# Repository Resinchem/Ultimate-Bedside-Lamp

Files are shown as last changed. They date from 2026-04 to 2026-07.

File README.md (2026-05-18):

# Ultimate Bedside Lamp
<div align="center">

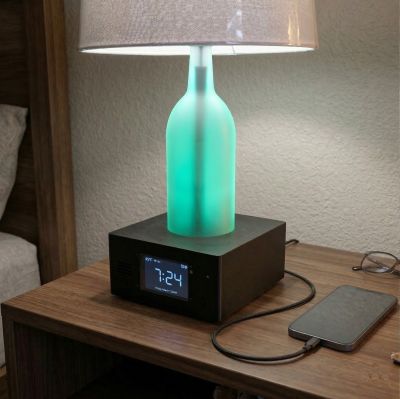
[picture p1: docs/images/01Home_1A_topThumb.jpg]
lamp_image

</div>

## Key Features
- **Integrated Hardware:** A single device providing lighting, clock and alarm functions.
   * Three independent ESP-based controllers act together as a single device
- **Versatile Lighting:** Indivdually controllable RGBW bulb and LED Strip for "normal" and "night" modes.
   * Each light source can have independent state, color and brightness settings
- **High-End Display:** Auto-dimming touch screen with configurable fonts, colors and sizes
   * Show time in 12 or 24-hour format.  Outdoor or indoor temperature in °F or °C.
   * Configurable dimming levels based on measured ambient light levels
   * Control lighting, set alarms and more right from the touch panel
- **Dual Touch Sensors:** Up to two configurable touch sensors
   * _Primary functions_: Toggle the lights, or change brightness of lights or the display with a simply tap.
   * _Special Alarm functions_: Buttons can automatically become alarm snooze/stop buttons when alarm sounds.
- **Advanced Alarms:** Define up to five active alarms
   * Allows long-term advanced scheduling and multiple active alarms can co-exist
   * **Gentle Wake Option:** Alarm sounds quietly and slowly increases in volume.
   * Selectable Alarm Sounds: Use one of the provided sounds or provide your own MP3 sounds
   * Customizable Snooze Range: Set your snooze time from 0-60 minutes.
- **Flexible Control Options**: Multiple methods provided for interacting with the system.
   * Single integrated web app 
   * Local touch controls via display and optional touch sensors
   * _Optionally_ integrate and control from external systems (e.g. Home Assistant, NodeRED, etc.)
- **Smart Integration**: Mutliple methods to _optionally_ interface with external systems
   * MQTT or HTTP API for exchanging data and controlling many features of the system.
   * **Home Assistant**: One-click integration with Home Assistant.  No configuration or YAML needed!
- **Local Control:** Only WIFI needed for full basic functionality.  Internet-based data use is **optional**
   * _Optionally_ sync time to an external NTP server (but also supports local server)
   * _Optionally_ get current weather/temperature from OpenWeatherSource (OWS)
- **Device Charging**: Dual USB ports for charging two devices simultaneously

### Guides, Instructions and More Information

- [Video Overview](https://youtu.be/4I0m3b1LWYo) - video overview of the project (YouTube)
- [Build Information](https://resinchemtech.blogspot.com/2026/04/ultimate-bedside-lamp.html) - written guide with parts list, wiring diagrams and general build instructions
- [Firmware Guide](https://resinchem.github.io/Ultimate-Bedside-Lamp/) - Instructions for installing, configuring and using the firmware and integrated web application.

Please review the above carefully.  For reasons described, this project expects a very specific set of hardware.  Substitutions will likely require firmware modifications.

**_I do not have the bandwidth to maintain multiple versions of the firmware for different hardware combinations. <br>Please do not submit issues requesting support for alternate hardware._** 

### Questions?
Can't find an answer above?  Please post your question in the [Discussion](https://github.com/Resinchem/Ultimate-Bedside-Lamp/discussions) are of the repository.  I will do my best to provide guidance as time allows.

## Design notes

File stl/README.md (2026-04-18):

## 3D Printed Parts Design Files
These are my design files (.stl) for the various 3D printed parts used. They were all creating using the simple, free Tinkercad web application and there is substantial room for improvement or redesign for someone with more talent than me!

|Part |Qty|Supports*|Est. Print Time* | Est. Filament*
|-----|:---:|:---:|:---:|:---:
|`Bottle Adapter.stl`|1|no|1 hour|5g
|`Bottle Center Shaft.stl`|1|no |7 hours| 40g
|`Bottle Platform.stl`|1|YES|3.5 hours| 30g
|`Bottle Sizer`|_optional_|no|2 hours|10g
|`Main Enclosure Base`|1|YES|**41 hours**|300g
|`Main Enclosure Lid`|1|no|10 hours| 90g
|`Midplatform Support`|1|no|1.5 hours|10g
|`USBPort Mount`|2|no|1 hour|6g
|`USBPort Nut`|2|no|1 hour|4g

- I used black PLA for all parts, but other materials/colors can be used if desired.  
- Estimates based on my printer and settings.  Yours may vary.
- Click on any .stl file above to see a 3D-generated preview of the part

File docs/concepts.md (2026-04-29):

---
layout: default
title: Concepts and Terminology
parent: Welcome
nav_order: 2
has_toc: false
---

# Concepts and Terminology
{: .no_toc }

To successfully install and configure this firmware, it is important to understand the underlying system design and the specific terminology used throughout this documentation.

**🌐 Connectivity & Privacy:**<br>This system is designed to be **fully functional on a local Wi-Fi network**. While it supports integrations like Home Assistant, Open Weather Map, and NTP time-syncing, these are strictly **optional**. An active internet connection is not required for core operations.
{: .note }

---

## The Controller Triumvirate
<p align="center">
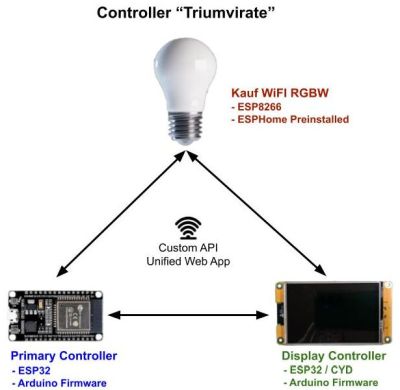
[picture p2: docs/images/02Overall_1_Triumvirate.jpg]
  
</p>
The "Ultimate Bedside Lamp" is not a single device, but a coordinated system of three separate controllers communicating via a custom internal API.

### 1. RGBW Wi-Fi Light Bulb
The bulb is the system's "Silent Partner." It arrives with a specialized version of ESPHome pre-installed, and it expects the rest of the world to keep up with its specific API. Think of it as the talented lead singer of the band who refuses to learn the other members' names—as long as the Primary Controller sends the right commands, the bulb performs beautifully. Just don't try to "re-educate" it with different firmware unless you're prepared for a very quiet (and dark) room. 

* **No Dependency:** You do **not** need to be a Home Assistant user or have an ESPHome server to use this bulb. It only requires a local Wi-Fi connection.
* **Integration:** If you are a Home Assistant user, you can _optionally_ import the bulb as an ESPHome node. Note that if you also integrate the Primary Controller via MQTT or Home Assistant Discovery, you may see duplicate entities for the bulb.
* **Firmware:** No flashing is required for the bulb. You will only need to complete the Wi-Fi onboarding process.

### 2. Primary Controller
This is a standard 30-pin **ESP32 WROOM32** running the custom Arduino-based firmware found in this repository. 
* **Action Required:** You must flash the provided firmware to this board and complete the onboarding process to join it to your local network.

Throughout this document, this controller is referred to as the **"Primary"** or **"Main"** controller.

### 3. Display Controller
This is a "Cheap Yellow Display" (CYD) featuring an integrated ESP32 and a 3.5" screen.

**⚠️ Critical Hardware Requirement**<br>The firmware is compiled specifically for the **Capacitive Touch** version of the 3.5" CYD linked in the build guide. This firmware **will not work** with resistive touch displays. Using a different display will require significant changes to the `TFT_eSPI` library and a full code recompilation.
{: .note }

* **Action Required**: Like the Primary Controller, this board requires flashing the firmware from the repository and Wi-Fi onboarding. 

This controller is always referred to as the **"Display"** or **"Secondary"** controller.

---

## Main Functions by Controller

The diagram below illustrates how responsibilities are divided across the three devices:

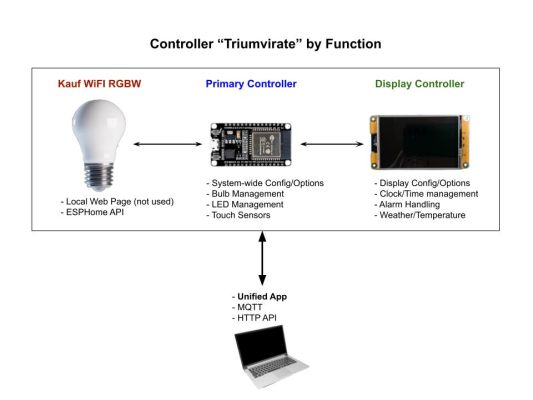
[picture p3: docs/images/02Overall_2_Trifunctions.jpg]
Controller By Function


### Unified Operation
While the hardware is split into three parts, the user experience is seamless:
* **Unified Web App:** Once onboarded, you access and control the entire system through a single web interface.
* **Single API/MQTT Path:** The system internally routes commands (API or MQTT) to the correct controller, allowing you to treat the lamp as a single entity in your automation logic.

---

For build instructions and physical assembly details, please refer to the [written companion guide](https://resinchemtech.blogspot.com/2026/05/ultimate-bedside-lamp.html).

<div style="display: flex; justify-content: space-between; align-items: center; margin-top: 40px; border-top: 1px solid #333; padding-top: 20px;">
  <a href="{{ '/about' | relative_url }}" class="btn btn-outline"><- Previous: About the Project</a>
  <a href="{{ '/startingmain' | relative_url }}" class="btn btn-purple">Next: Getting Started -></a>
</div>

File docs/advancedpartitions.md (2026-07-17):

---
layout: default
title: Partitions and Flashing
parent: Advanced Technical Information
nav_order: 4
---

# Partitions and Flashing
{: .no_toc }

---

<p align="center">
  [Partitions image]
</p>

This information is critical if you are manually flashing source code via the Arduino IDE or a third-party utility. If you are simply using the web-based "Firmware Upgrade" feature with the provided `.bin` files, the system handles the memory offsets for you. However, for the developers out there, here is how we manage the "real estate" inside the ESP32.

### The "Sketch Too Large" Problem
Due to the complexity of the firmware and the inclusion of the web application strings, the binary is too large to fit into a standard ESP32 partition. To solve this, we "borrow" space normally reserved for the SPIFFS (the local file system). Since our configuration files are tiny JSON strings, we can safely shrink the SPIFFS area and give that extra room to the primary sketch.

**🖥️ Full vs. Update .bin Files**<br>This partitioning is why the releases contain both a **_Full.bin** and a **_Update.bin** file.  When flashing the **_Full.bin** file, the new partitions are created as part of the installation.  This will cause the destruction and loss of any pre-existing data, which is why upgrading an existing system with the **_Full.bin** file causes loss of the existing configuration.  Alternatively, attempting to install the **_Update.bin** file on a new board only updates the sketch area, but since the correct partitions do not exist, it gets written to the wrong area and generally results in a boot loop.
{: .note }

---

### Arduino IDE Configuration
When using the Arduino IDE to compile and flash the source code, you **must** change the partition scheme from the "Default" setting. Failure to do this will result in a compilation error stating that the firmware is too large for the available space.

In the **Tools** menu, ensure your settings match the following:

* **Board:** `ESP32 Dev Module`
* **Partition Scheme:** `Minimal SPIFFS (1.9MB APP with OTA/190KB SPIFFS)`

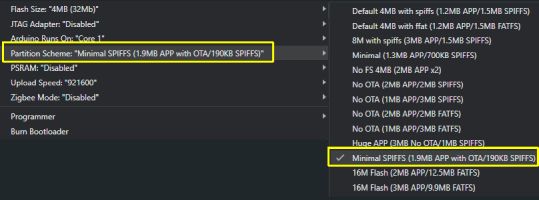
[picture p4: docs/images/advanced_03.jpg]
Arduino IDE Partition Settings


---

### Manual Partition Table
If you are using a different IDE or a specialized flashing utility (like the Espressif Download Tool), you will need the specific memory offsets and sizes. If these aren't set correctly, the ESP32 will likely fall into a "boot loop" as it tries to find its code in the wrong neighborhood.

| Partition Name | Type | Subtype | Offset | Size |
| :--- | :--- | :--- | :--- | :--- |
| **nvs** | data | nvs | `0x9000` | `0x5000` (20KB) |
| **otadata** | data | ota | `0xe000` | `0x2000` (8KB) |
| **app0** | app | ota_0 | `0x10000` | `0x1E0000` (1.875MB) |
| **app1** | app | ota_1 | `0x1F0000` | `0x1E0000` (1.875MB) |
| **spiffs** | data | spiffs | `0x3D0000` | `0x30000` (~190KB) |

> **💡 Fun Fact**<br>By using this "Minimal SPIFFS" layout, we still have two identical `app` slots (OTA0 and OTA1). This is what allows a controller to perform a "Safe Update"—it downloads the new firmware into the empty slot and only switches over if the download is successful. It’s like wearing a belt and suspenders at the same time!
{: .note }

---

<div style="display: flex; justify-content: space-between; align-items: center; margin-top: 40px; border-top: 1px solid #333; padding-top: 20px;">
  <a href="{{ '/advanceddisplay' | relative_url }}" class="btn btn-outline"><- Previous: Display Library and Fonts</a>
  <a href="{{ '/troubleshooting' | relative_url }}" class="btn btn-purple">Next: Troubleshooting -></a>
</div>

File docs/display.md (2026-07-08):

---
layout: default
title: Main Display
parent: Setting Up the System
nav_order: 2
---

# Display Settings and Options
{: .no_toc }

---

<p align="center">
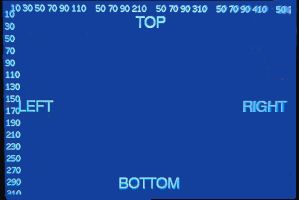
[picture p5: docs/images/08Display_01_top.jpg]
Main Display Overview
  
</p>

The main display is a 3.5" 'Cheap Yellow Display' (CYD) featuring capacitive touch and a resolution of 480x320 pixels. 

> **⚠️ Hardware Compatibility**<br>As detailed in the [Build Article](https://resinchemtech.blogspot.com/2026/05/ultimate-bedside-lamp.html), using a different display model will likely require firmware modifications, specifically within the **TFT_eSPI** library configuration. 
{: .important }

---

### Configuring the Display
To access the display settings, navigate to the **Display** section of the primary web application. Note that the interface will switch to the Display Controller, indicated by a pale yellow background.

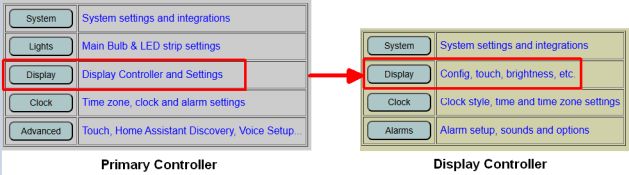
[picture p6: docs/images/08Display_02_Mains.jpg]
Display Interface Menu


The configuration page is divided into two sections. The top section manages the hardware behavior and orientation of the display itself.

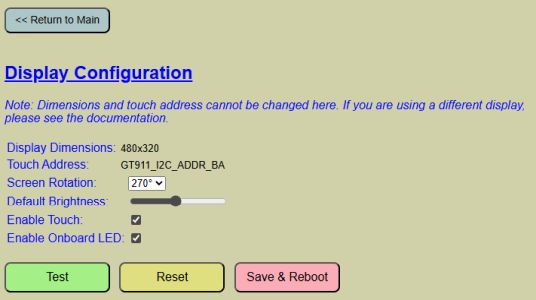
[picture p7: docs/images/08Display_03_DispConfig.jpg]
08_Display_03


#### Hardware Definitions
* **Dimensions & Touch Address:** These values are hard-coded in the TFT_eSPI library during firmware compilation and cannot be changed via the web app. If you are using non-standard hardware, refer to [Modifying the Firmware]({{ '/firmwaremain' | relative_url }}).
* **Screen Rotation:** Options include 0°, 90°, 180°, and 270° (Default). 
    * **Note:** The firmware is optimized for landscape (90°/270°). Portrait orientations may result in text being cut off. 

#### Operational Settings
* **Default Brightness:** Sets the initial brightness level after a reboot. If [Auto-Dimming]({{ '/autodim' | relative_url }}) is enabled, this value is overridden by ambient light levels, though it is still used as the "base" brightness when the screen is tapped.
* **Enable Touch:** This controls the capacitive touch features of the display. 
    > **⚠️ Warning**<br>If you disable this feature, you will lose the ability to access settings or menus directly via the display. Only uncheck this if your hardware does not support capacitive touch.
    {: .warning }
* **Enable Onboard LED:** If your display hardware includes a front-facing RGB LED, this option allows it to show system status.
    * **Yellow:** Booting/Process in progress.
    * **Green:** Successful connection/boot.
    * **Red:** Failure or Test Mode.
<br><br>
<p align="center">
  Main Display Overview
</p>

### Testing and Maintenance
The system provides built-in tools to verify your display and touch configuration without requiring a reboot.

* **TEST Button:** Activating this shows the visual boundaries of the screen, scale indicators, and lights the onboard LED red. 
* **Touch Testing:** If touch is enabled, you can drag your finger to draw lines, confirming the calibration and responsiveness of the screen.

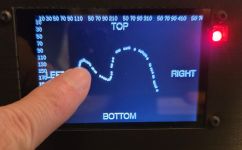
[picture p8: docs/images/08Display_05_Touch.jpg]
Touch Test Mode


* **RESET Button:** Reverts all unsaved changes on the page to the previously saved defaults.
* **SAVE AND REBOOT:** Commits current settings to the flash memory and restarts the controller to apply them. **Unsaved changes are lost if you navigate away from this page.**

---

### The Standard Clock Display
When idle, the display shows the clock and environmental data. Several status icons are positioned along the top edge:

<p align="center">
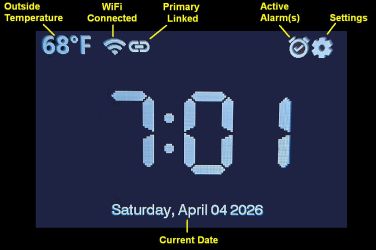
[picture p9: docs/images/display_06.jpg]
Clock Display Layout
  
</p>

* **Outside Temperature:** Displays the local outdoor temperature. This requires a configured source such as Open Weather Map, MQTT, or the HTTP API. Refer to [Temperature and Weather]({{ '/weather' | relative_url }}) for setup.
* **WiFi:** Indicates connection status. A slash indicates the display controller is offline WiFi Icon.
* **Primary Link:** Indicates a successful API connection to the Primary Controller. Shown with slash if not connectedLink Icon
* **Active Alarms:** Only appears when one or more alarms are scheduled and active.
* **Settings:** Tapping this icon enters the local settings menu for lighting and alarm control. Details can be found in [Using the System]({{ '/usingmain' | relative_url }}).
* **Time:** The core clock display. Font, color, and 12/24-hour formats can be modified under [Clock and Time Options]({{ '/time' | relative_url }}).
* **Date:** The current date is shown on the bottom of the display.  This is also set as part of the time.

---

<div style="display: flex; justify-content: space-between; align-items: center; margin-top: 40px; border-top: 1px solid #333; padding-top: 20px;">
  <a href="{{ '/webapp' | relative_url }}" class="btn btn-outline"><- Previous: Web App Overview</a>
  <a href="{{ '/autodim' | relative_url }}" class="btn btn-purple">Next: Auto-Dimming -></a>
</div>

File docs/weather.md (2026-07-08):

---
layout: default
title: Temperature and Weather
parent: Setting Up the System
nav_order: 6
---

# Setting Up a Weather Source
{: .no_toc }

---

<p align="center">
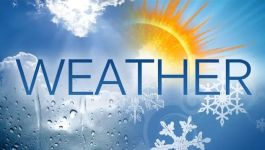
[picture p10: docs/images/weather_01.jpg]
Weather Display Overview
  
</p>

Currently, the system only uses temperature data, though future updates may add additional features from external weather sources. While designed for outdoor temperature, you can easily use it for indoor temperature by simply changing the source.

> **💡 Note: Hardware Limitation**<br>The system does not have its own temperature sensor; it simply displays the value it receives from an external source. Until a weather source is configured, the clock will display an initial temperature of **0°**.
{: .note }

To access the weather integration settings, return to **System Integrations** from the primary controller's main web page.

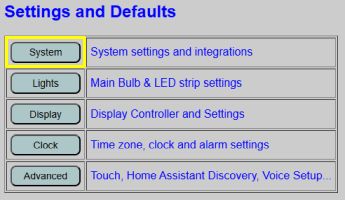
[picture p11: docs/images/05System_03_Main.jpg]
05System_03


The weather settings are located at the bottom of the System Integrations page.

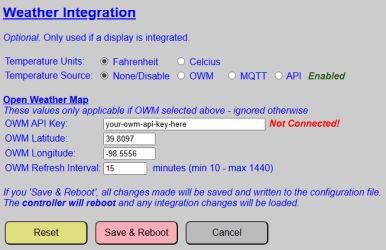
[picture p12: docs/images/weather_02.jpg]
Weather Integration Section


### Temperature Units and Source
* **Temperature Units:** Select between **°F** or **°C**.
* **Temperature Source:**
    * **None:** Disables the temperature display.
    * **OWM (Open Weather Map):** A free* service using your coordinates for local data. _Requires an internet connection_.
    * **MQTT:** Receives temperature via your MQTT broker. See [MQTT Setup and Topics]({{ '/mqtt' | relative_url }}) for more info.
    * **API:** Updates only when a valid HTTP API command is received. See the [API HTTP Command List]({{ '/api' | relative_url }}) for details.

---

### Open Weather Map Configuration
These settings are only used if **OWM** is selected. You must create an account at [OpenWeatherMap.org](https://openweathermap.org/) to generate an API key.

<p align="center">
  OWM Config Interface
</p>

> **⚠️ Important: API Limits and Billing**<br>The system uses the **One Call 3.0 API**. While this is free for up to **1,000 calls per day**, Open Weather Map requires a credit card on file for this tier. If you exceed 1,000 calls in a single day, charges will be incurred. 
{: .important }

To ensure you stay well within the free limit, the system enforces a **minimum refresh interval of 10 minutes** (maximum 144 calls/day).

#### OWM API Key

> 🔍 Generating an API key is a bit of a "quest" that involves signing up for an account and waiting for the key to activate (which can take a few hours). Don't blame the lamp if the key doesn't work instantly—OpenWeatherMap's servers need a little time to realize you’ve joined the party.
{: .note}

Once generated, copy and paste your API key into the OWM API Key field. You can use unique keys for different services (like Home Assistant) to track usage independently, but all calls count towards the 1,000 calls/day limit regardless of key used.

OWM API Key Field

#### OWM Latitude and Longitude
Enter your specific coordinates. If you don't know them, you can find them by clicking your location in Google Maps.

> **⚠️ Important: Negative Coordinates**<br>Depending on your location, your latitude or longitude may be a negative number. You **must** include the negative sign (`-`) in the field or the system will pull weather for the wrong hemisphere.
{: .important }

#### OWM Refresh Interval
This specifies how often the system polls the server. The minimum is **10 minutes** and the maximum is **1,440 minutes** (once per day).

---

### Page Buttons

> **⚠️ Important: Global Impact**<br>Unlike other sections of the web app, the System Integration page buttons **apply to ALL settings on the page simultaneously**. 
{: .important }

* **Reset Button:** Reloads all saved configuration values. This affects OWM settings AND all other system integrations on the page.
* **Save and Reboot Button:** Commits ALL integration settings to the configuration file and reboots the controller. Verify all values on the page (WiFi, MQTT, etc.) before clicking this.
* **Cancel Button:** Discards all changes and returns to the controller's main page.

<div style="display: flex; justify-content: space-between; align-items: center; margin-top: 40px; border-top: 1px solid #333; padding-top: 20px;">
  <a href="{{ '/time' | relative_url }}" class="btn btn-outline"><- Previous: Clock and Time Settings</a>
  <a href="{{ '/touchsensors' | relative_url }}" class="btn btn-purple">Next: Touch Sensor Configuration -></a>
</div>

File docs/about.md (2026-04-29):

---
layout: default
title: About this Project
parent: Welcome
nav_order: 1
has_toc: false
---

# About this Project
{: .no_toc }

---

<p align="center">
  Ultimate Bedside Lamp prototype
</p>

## The Problem

My nightstand had reached a state of "technological junk-drawer." Between the standalone clock, the lamp, the remote for an LED strip, and a tangled web of charging cables, it looked less like a bedroom and more like the bargain bin at a 1998 RadioShack&trade;. I needed one device to rule them all—or at least one that didn't require a search-and-rescue team to find the "Snooze" button at 6:00 AM.  

Most retail devices also suffered from at least one or more of the following issues:

* **Display Issues:** Screens were often too bright for a dark bedroom, or the digits were too small to read at night without glasses.
* **Audio Issues:** Jarring buzzers or beeps with no volume control made for a stressful wake-up experience.
* **Lack of Control:** Until recently, most systems offered no way to integrate with modern smart home automation.

For the lighting, I needed a true "night light" mode—dim enough for middle-of-the-night trips without ruining night vision, yet bright enough for reading. I also wanted to eliminate the clutter of multiple power cables needed to charge devices every night.

This project is the result of those requirements: an all-in-one system I call the **Ultimate Bedside Lamp**.

---

## The Solution
This build was designed to address my specific pain points while adding several modern features:

* **Integrated Hardware:** A single device providing lighting, clock, and alarm functions.
* **Versatile Lighting:** Uses an RGBW bulb and an LED strip for "Normal" and "Night" modes.
* **High-End Display:** Auto-dimming touch screen with configurable fonts, colors and sizes.
    * Show time in 12 or 24-hours format.  Outdoor temperature in °F\°C
    * Configurable dimming levels based on measured ambient light level
    * Control lighting, set alarms and more right from the touch screen panel
* **Dual Touch Sensors:** Configurable touch sensors for controlling lights, snoozing/stopping alarms, etc.
* **Advanced Alarms:**
    * Multiple simultaneous alarms and long-term scheduling.
    * **Gentle Wake:** Audio starts quietly and slowly increases in volume.
    * Selectable alarm sounds (or use you own MP3s) and customizable snooze (0–60 minutes).
* **Flexible Control Options:** Manage via integrated web app, local touch controls or integrated with external systems.
* **Device Charging:** Dual USB ports for charging two devices simultaneously
* **Smart Integration:** Multiple methods to _optionally_ interface with external systems.
    * MQTT or HTTP API for exchanging data and controlling many features of the system
    * **Home Assistant**: One click integration with Home Assistant. No configuration or YAML needed!
* **Local Control:** Operates fully over Wi-Fi with only optional external data use.

---

## Caveats and Hardware Support
This system was built for my specific needs. The firmware is tightly coupled with the hardware components selected.

**⚠️ Technical Requirement**<br>The touch panel utilizes the [TFT_eSPI](https://github.com/Bodmer/TFT_espi) library. To use a display different than mine, you must define your specific display in the library's configuration, which requires compiling and flashing your own version of the firmware.
{: .note }

The [written guide](https://resinchemtech.blogspot.com/2026/04/ultimate-bedside-lamp.html) includes a detailed parts list indicating which components are interchangeable and which will require code modifications.

**I do not have the bandwidth to maintain multiple versions of the firmware for different hardware combinations. Please do not submit issues requesting support for alternate hardware.**
{: .label .label-yellow }

### Questions?
If you can't find an answer here or in the companion [Build Guide](https://resinchemtech.blogspot.com/2026/05/ultimate-bedside-lamp.html), please post your question in the [Discussion](https://github.com/Resinchem/Ultimate-Bedside-Lamp/discussions) are of the repository.  I will do my best to provide guidance as time allows.

<div style="display: flex; justify-content: space-between; align-items: center; margin-top: 40px; border-top: 1px solid #333; padding-top: 20px;">
  <a href="{{ '/' | relative_url }}" class="btn btn-outline"><- Previous: Welcome</a>
  <a href="{{ '/concepts' | relative_url }}" class="btn btn-purple">Next: Concepts & Terminology-></a>
</div>

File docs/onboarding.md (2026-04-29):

---
layout: default
title: Onboarding and First Time Setup
parent: Getting Started
nav_order: 2
has_toc: false
---

# Onboarding and First Time Setup
{: .no_toc }

---

<p align="center">
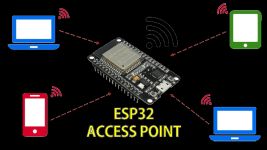
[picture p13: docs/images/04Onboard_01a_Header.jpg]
Onboarding Header
  
</p>

Once you have successfully flashed the firmware to your Primary and Display controllers, the next step is to connect them—along with your RGBW bulb—to your local Wi-Fi network. 

**🌐 Local Network Reminder**<br>While these devices require a Wi-Fi connection to communicate with each other, they **do not** require active internet access for core functionality. External services (like Home Assistant or OpenWeatherMap) are entirely optional.
{: .note }

---

## 1. Kauf RGBW Wi-Fi Bulb
Follow the instructions provided with your bulb to complete its initial Wi-Fi setup. While the process is similar to the controllers below, there is one specific detail you must capture for the system to function: the **ESPHome Device Name**.

### Finding the Device Name
After WIFI onboarding, and if you are not using Home Assistant, locate the IP address assigned to the bulb by your router and enter it into a web browser. This opens the bulb’s native interface.

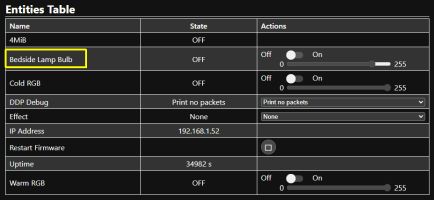
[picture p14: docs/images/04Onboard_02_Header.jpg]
04Onboard_02_Header


The default name is typically something like `Kauf Bulb 8a37db`. If you choose to rename the bulb (via Home Assistant or the ESPHome dashboard), ensure you do so **before** configuring the lamp's interface settings.

### Converting to the "HA Standard"
Later in the setup, you will need to provide the bulb's name in the **Home Assistant entity format**. 
* **The Rule:** Convert all letters to lowercase and replace all spaces with underscores (`_`).

| Original Name | HA Entity Format |
| :--- | :--- |
| Bedside Lamp Bulb | `bedside_lamp_bulb` |
| Kauf Bulb 8a37db | `kauf_bulb_8a37db` |

*Note: Write down both the bulb's **IP Address** and this **Entity Name**.*

---

## 2. Primary and Display Controllers
You must perform this process twice—once for each controller. 

### Step 1: Join the Hotspot
Once flashed, the controller will broadcast its own Wi-Fi network. It’s essentially a very tiny, very exclusive club where the only item on the menu is "Configuration." If your phone warns you that the "Network has no Internet access," take a deep breath and tell it everything is fine. We aren't here to browse cat memes; we’re here to give a lamp its identity.

The default hotspot names for the Wi-Fi hotspots are:
* **Primary:** `BedsideLamp01_AP`
* **Display:** `BL_Display01_AP`

_As noted earlier, these hotspot names may show your assigned DeviceName_AP instead of the above._

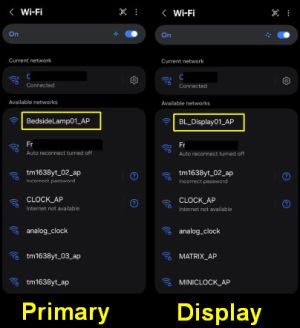
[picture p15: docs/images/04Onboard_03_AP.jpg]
04Onboard_03_AP


Use a phone, tablet, or laptop to join the hotspot. Remember, if your device warns you that there is "No Internet Connection," select **Stay Connected**.

### Step 2: Access the Onboarding Form
Open a web browser and enter the IP address: **`192.168.4.1`**. The onboarding form will appear:

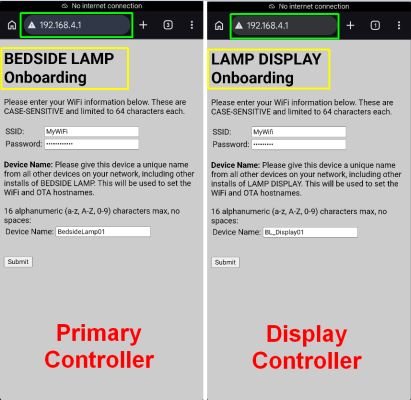
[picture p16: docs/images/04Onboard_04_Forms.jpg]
04Onboard_04_Forms


Fill out the following fields:
* **SSID:** Your Wi-Fi network name (must be the same for all three devices).
* **Password:** Your Wi-Fi password.
* **Device Name:** A unique, short name (up to 16 alphnumeric characters plus the underscore (_), no spaces). 
    * *Example:* `lamp_primary` and `lamp_display`. 
    * Each controller on your network **must** have a unique name.

### Step 3: Submit and Verify
Click **Submit**. The controller will reboot and attempt to join your network. If successful, the hotspot will disappear. You should now be able to see the device and its new IP address in your router’s client list.

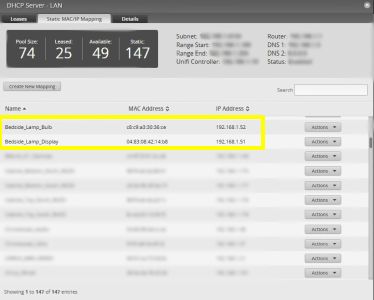
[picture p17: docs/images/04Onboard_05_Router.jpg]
04Onboard_05_Router


---

## 3. Assign Static or Reserved IP Addresses
**This step is strongly recommended for system stability.**
{: .label .label-yellow }

The controllers communicate with each other using IP addresses. If your router reassigns a new IP to one of the devices (due to a power failure or lease expiration), the system will stop functioning.

1. Open your router's configuration page.
2. Create a **Static Reservation** for the Bulb, Primary Controller, and Display Controller.
3. Power cycle each device to ensure they are using the newly assigned static IPs.

---

## 4. Final Hardware Integration
At this point, you should move your controllers from your computer to their final positions (either on a breadboard or inside the lamp housing). 

**It is critical to connect all peripherals** (touch sensors, LED strips, DFPlayer, etc.) before proceeding. The firmware looks for these components during the boot process; if they are missing, the system may not initialize correctly.

### Build Resources
If you haven't completed the physical build yet, refer to these guides:
* **[YouTube Overview]({{site.links.youtube_video}})**
* **[Written Build Guide](https://resinchemtech.blogspot.com/2026/05/ultimate-bedside-lamp.html)**

Once your hardware is connected and powered, proceed to the [System Interfaces]({{ '/interfaces' | relative_url }}) section.

<div style="display: flex; justify-content: space-between; align-items: center; margin-top: 40px; border-top: 1px solid #333; padding-top: 20px;">
  <a href="{{ '/installation' | relative_url }}" class="btn btn-outline"><- Previous: Installation</a>
  <a href="{{ '/interfaces' | relative_url }}" class="btn btn-purple">Next: System Interfaces -></a>
</div>

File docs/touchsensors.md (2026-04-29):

---
layout: default
title: Touch Sensors
parent: Setting Up the System
nav_order: 7
---

# Defining and Using the Touch Sensors
{: .no_toc }

---

<p align="center">
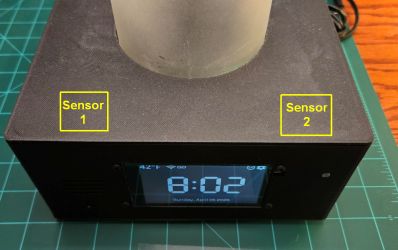
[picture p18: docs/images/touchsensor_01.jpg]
Touch Sensor Placement
  
</p>

If built as described in the [Build Article](https://resinchemtech.blogspot.com/2026/05/ultimate-bedside-lamp.html), the lamp includes two TTP223 capacitive touch sensors mounted under the lid. These sensors are highly sensitive and function through non-conductive materials like PLA (tested up to 5mm) or wood.

> **⚠️ Material Warning**<br>Touch sensors will not function through metallic or other conductive surfaces. Additionally, ensure the sensors are placed at least 3-4 inches (7-10 cm) apart; if they are too close, triggering one may accidentally trigger the other.
{: .warning }

> **🔍 Dealing with Ghosts in the Machine**<br>Capacitive touch is magic until it isn't. If your lamp starts turning itself on and off like it's haunted, your sensitivity thresholds are likely set too low. High humidity or a stray charging cable resting near the sensor can trick the ESP32 into thinking a finger is present. Unless you're looking for a supernatural roommate, a quick adjustment to the duration usually clears things up.  If necessary, you can also add a capacitor to the TTP223 sensor to reduce its native sensitivity.
{:  .note }

---

### Configuring the Sensors
The touch control settings are found under the **Advanced** settings on the primary controller's main web page.

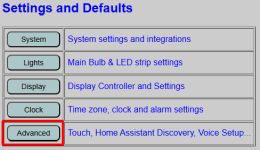
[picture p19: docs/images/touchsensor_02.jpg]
Advanced Settings Menu


Each sensor is configured independently. You must check the **Enable** box for each sensor you have installed to allow the firmware to read the hardware.

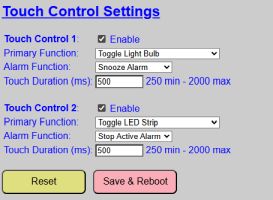
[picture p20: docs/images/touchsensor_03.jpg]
Touch Sensor Config Interface


***Dual-Function Logic***<br>
Each sensor can be assigned two distinct roles based on the current state of the lamp:
* **Primary Function:** The action executed when a touch is detected while the alarm is idle or in a "Snooze" state.
* **Alarm Function:** The action executed specifically while an alarm is actively sounding.

---

### Primary Function Options
When the lamp is in its normal state, you can select from the following actions:

Primary Function List

* **None:** No internal action is taken.
    > **💡 MQTT Integration**<br>Even if set to **None**, a sensor will still send an MQTT message if MQTT is enabled. This allows you to use the touch sensors to trigger external automations in Home Assistant without affecting the lamp's internal state.
    {: .note }
* **Toggle Light Bulb / LED Strip:** Taps toggle the power state (On/Off).
* **Brightness Controls (Bulb & LED Strip):** Taps increase or decrease brightness by ~10%. 
    * **Wrap-Around:** Reaching 100% brightness and tapping again will "wrap" the value back to the dimmest setting.
    * **Note:** The light must be **ON** for these touches to register; they will not turn on a light that is currently off.
* **Brightness Controls (Display):** Increases or decreases display brightness by ~10%.
    * **No Wrap:** Unlike the lights, the display brightness will **not** wrap around. It will stay at the maximum or minimum value.
    > **💡 Auto-Dim Override**<br>If [Auto-Dimming]({{ '/autodim' | relative_url }}) is enabled, it will eventually overwrite manual brightness changes made via touch. If your display brightness "snaps back" after a touch, check your Auto-Dim settings.
    {: .note }

---

### Alarm Function Options
The Alarm Function is active only while an alarm is sounding. If an alarm is currently snoozed, the sensors revert to their **Primary Function** until the alarm resumes.

Alarm Function List

* **None:** No action is taken when the sensors are tapped during an actively sounding alarm.
* **Snooze Alarm:** Taps trigger the snooze period. The sensor then returns to its primary function until the snooze expires.
* **Stop Alarm:** Taps fully deactivate the sounding alarm. The sensor returns to its primary function immediately.

---

### Touch Duration (Debounce)
The **Touch Duration** (entered in milliseconds) determines how long a finger must remain on the sensor for a touch to register. This acts as a hardware "debounce."

> **💡 Calibration Hint**<br>Because these sensors are extremely sensitive, a single quick tap might register as 2 or 3 separate touches (e.g., toggling a light on and immediately back off). A value of **500 ms** is a good starting point. If you experience "double-touches," slowly increase this value. The range is 250 ms to 2,000 ms.
{: .note }

---

### Combining Sensor Uses
By utilizing two sensors with dual functions, you can create versatile control schemes. 

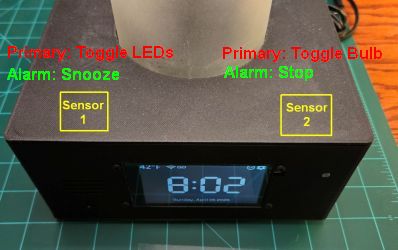
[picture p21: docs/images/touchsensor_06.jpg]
Sensor Combination Example


In this common setup:
1. **Normal State:** Left sensor toggles the LED strip; Right sensor toggles the Bulb.
2. **Alarm State:** Left sensor becomes "Snooze"; Right sensor becomes "Stop."
3. **Morning Workflow:** When the alarm sounds, you can tap the Left sensor to snooze. Later, when it sounds again, tap the Right sensor to stop the alarm. Because the sensor immediately reverts to its primary function, a second tap on that same Right sensor will turn on the main light bulb for you.

---

### Maintenance
* **RESET:** Reverts only the Touch Sensor section to the last saved defaults.
* **SAVE AND REBOOT:** Commits settings to flash memory and restarts the controller. **Note:** You must save and reboot to test different configurations, as there is currently no "Live Test" button for touch sensors.

---

<div style="display: flex; justify-content: space-between; align-items: center; margin-top: 40px; border-top: 1px solid #333; padding-top: 20px;">
  <a href="{{ '/weather' | relative_url }}" class="btn btn-outline"><- Previous: Temperature and Weather</a>
  <a href="{{ '/usingmain' | relative_url }}" class="btn btn-purple">Next: General System Use-></a>
</div>

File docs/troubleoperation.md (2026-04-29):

---
layout: default
title: Daily Operation & Configuration
parent: Troubleshooting
nav_order: 2
---

# Daily Operation & Configuration
{: .no_toc }

---

<p align="center">
  [PLACEHOLDER: Daily Operation Troubleshooting]
</p>

If your lamp is up and running but you find that settings aren't sticking or updates aren't applying, you’ve likely encountered a configuration "hiccup." This section covers how the system saves data and how to verify what’s actually happening under the hood.

## Configuration & Persistence Issues
If you make changes to your setup and they seem to vanish after a reboot, check the following:

### RTFM! (**R**ead **T**he **F**\*\*\*\*\*g **M**anual!)
It sounds harsh, but it’s the most effective fix. Ensure you’ve reviewed the applicable sections in this guide and the [Build Guide](https://resinchemtech.blogspot.com/2026/05/ultimate-bedside-lamp.html). Most "bugs" turn out to be a result of missed instructions or incorrect assumptions about how the firmware handles specific hardware.

### Check Release Notes
If you recently performed an upgrade, read the release notes for **Breaking Changes**. Occasionally, a new version requires a change to the underlying `config.json` structure, which might require a post-update manual tweak.

### The "Save & Reboot" Button Logic
Many pages in the web app are divided into sections, each with its own **Save & Reboot** button.

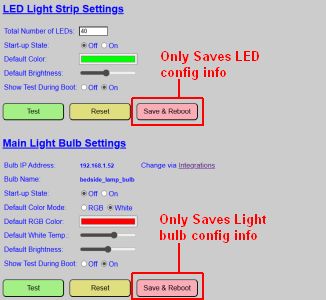
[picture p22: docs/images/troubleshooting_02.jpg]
Save Button Logic


As shown above, a save button only captures the data in its *specific* section. If you change the LED settings **and** the Light Bulb settings but only click the top "Save & Reboot" button, your bulb changes will be lost. 

> **💡 Why the multi-save approach?**<br>Placing every single option on one giant page would overwhelm the ESP32's modest web server. By modularizing the saves, we ensure the controller stays responsive and only updates the specific segments of memory that actually changed.
{: .note }

## Reviewing the "Source of Truth"
If the web UI is being coy, you can look at the raw data. Use the **Config Dump** command in the [Controller Commands]({{ '/commands' | relative_url }}) menu to see the JSON files. 

If the web app won't load at all, connect via USB and use [ESPConnect](https://thelastoutpostworkshop.github.io/ESPConnect/) to view the filesystem.

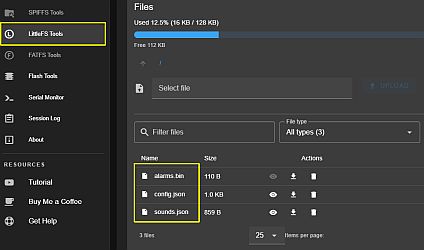
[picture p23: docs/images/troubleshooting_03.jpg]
ESPConnect File View


> **⚠️ Warning: Hands Off the Trash Can**<br>Do not delete configuration files via ESPConnect unless you are prepared for a full re-onboarding. While you can use the "eye" icon to view `config.json` or `sounds.json`, manually editing or deleting these can render the system unbootable.
{: .warning }

## Firmware Update Issues
If a wireless update via the web app fails (or the version number doesn't change after a reboot), follow these steps:

1. **Verify the File:** Double-check that you aren't trying to flash the Primary firmware to the Display controller (or vice versa).
2. **Retry the Transfer:** Wireless interference can occasionally drop a packet. Try the process one more time.
3. **Power Cycle:** Fully unplug the controller, plug it back in, and then attempt the update.

If the internal update continues to fail, use **ESPConnect** via USB. Just ensure you **uncheck** the "Erase Flash" option, or you'll be starting over from scratch!

---

<div style="display: flex; justify-content: space-between; align-items: center; margin-top: 40px; border-top: 1px solid #333; padding-top: 20px;">
  <a href="{{ '/troublesetup' | relative_url }}" class="btn btn-outline"><- Previous: Initial Setup Issues</a>
  <a href="{{ '/troublediscovery' | relative_url }}" class="btn btn-purple">Next: Home Assistant & MQTT Issues-></a>
</div>

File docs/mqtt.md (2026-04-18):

---
layout: default
title: MQTT Setup & Topics
parent: Using MQTT and the API
nav_order: 1
---

# MQTT Setup and Topics
{: .no_toc }

---

<p align="center">
  MQTT Overview
</p>

If you wish to use MQTT with the system, you must meet a few prerequisites and also enable and configure MQTT in the web application.

## Prerequisites
To use MQTT you must have a local MQTT broker available on your network. While you can technically use a cloud-based MQTT provider, this is not recommended due to the lag introduced between sending a command and having it received by the system. One of the most popular free local versions is [Eclipse Mosquitto](https://mosquitto.org/).

If you are a Home Assistant user, you can turn Home Assistant into your MQTT broker by installing the MQTT broker app/add-on.

## Understanding Topics
MQTT works using a subscribe/publish method. The system allows you to define these topics, and your external system must use these same topics for proper communication.

* **Publish (stat/):** All messages sent by the lamp are published to a topic prepended with `stat/`.
* **Subscribe (cmnd/):** All topics subscribed to by the lamp are prepended with `cmnd/`.

## Enabling and Configuring MQTT
MQTT configuration is found under the primary controller's **System Settings and Integrations**.

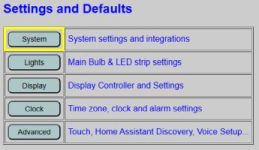
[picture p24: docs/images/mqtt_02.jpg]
Accessing Integrations


The MQTT setup section is located near the bottom of the page.

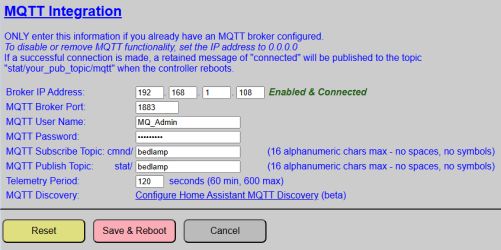
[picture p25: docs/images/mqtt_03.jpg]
MQTT Configuration Interface


* **Broker IP Address:** Enter the IP address of your MQTT broker.
* **MQTT Broker Port:** Default is `1883`.
* **MQTT User Name / Password:** Enter the account credentials for your broker.
* **Subscribe Topic:** Specify up to 16 alphanumeric characters. The system prepends `cmnd/`. Example: `cmnd/bedlamp/*`.
* **Publish Topic:** Specify up to 16 alphanumeric characters. The system prepends `stat/`. Example: `stat/bedlamp/`.

> **⚠️ Topics**<br>For most brokers, topics are **case-sensitive**.  As a best practice, only use lowercase letters and numbers in your topics.  Spaces and symbols are not permitted.
{: .warning }

> **💡 Integration Tip**<br>Since the system prepends `stat/` and `cmnd/` automatically, you can use the same string for both (e.g., `bedlamp`) to simplify your naming convention.
{: .note }

### Maintenance & Buttons
> **⚠️ Important: Global Page Buttons**<br>Unlike some other settings pages, there is only ONE set of buttons at the bottom of the page. These buttons apply to **ALL** fields and integrations on the page (WiFi, Weather, etc.).
{: .important }

* **Reset Button:** Restores any changed values back to the current saved configuration.
* **Save and Reboot:** Saves all current values on the page. Both the **Primary and Display** controllers will reboot. The system will start publishing/subscribing to MQTT topics upon completion of the boot.
* **Cancel Button:** Discards changes and returns to the main menu.

## MQTT State (Publish) Topics
The system publishes current values and diagnostic data to the broker. All state topics are published with the **Retain** flag set to **TRUE**.

### Diagnostic / Boot Topics
These values are published only at boot time, except for LWT (status) which is updated by the broker.<br> Formatted as `stat/[your-publish-topic]/[topic-suffix]`.

|Topic Suffix|Payload Type|Example/Range|Notes|
|:---|:---:|:---:|:---|
|`/bulb/ipaddr`|String|192.168.1.52|RGBW Light Bulb IP address|
|`/bulb/status`|String|online or offline|Bulb Last will and testament. (LWT)|
|`/display/ipaddr`|String|192.168.1.51|Display controller's IP address|
|`/display/lastboot`|date-time string| 2026-04-02 14:38|Date/Time display last booted|
|`/display/macaddress`|String|08:B6:1F:3C:1F:B0|WIFI MAC address of display ESP32|
|`/primary/ipaddr`|String|192.168.1.50|Primary controller's IP address|
|`/primary/macaddress`|String|04:83:08:42:14:B8|WIFI MAC address of primary ESP32|

### Entity State Topics
Formatted as `stat/[your-publish-topic]/[topic-suffix]`.

|Topic Suffix|Payload Type|Example/Range|Notes|
|:---|:---:|:---:|:---|
|`/alarms`|JSON |*See note below|A JSON array of current alarm sesttings|
|`/alarmtrack`|number| 0 - 20 |Indicates the current index/track for alarm sound|
|`/alarmvolume`|number|0 - 30|Current max volume level for alarms|
|`/gentlewake`|ON / OFF|ON|Current state of the alarm Gentle Wake feature|
|`/snoozetime`|number|0 - 60|Snooze length duration (in minutes)|
|`/bulbbrightness`|number|0 - 255|Current brightness level of the light bulb|
|`/bulbcolor`|String| 255,0,0|Red, green, blue values for current bulb color. Will be updated to white (255,255,255) when bulb is in color_temp mode.|
|`/bulbmode`|String| 'color_temp' or 'rgb'|Last mode of the light bulb.|
|`/bulbstate`|String| ON or OFF|Current state of the light bulb. Always published in upper case.|
|`/bulbtemp`|number| 150 - 350 | White temperature, in mireds, when the bulb is in color_temp mode.|
|`/clockcolor`|Hex String|#ffffff|Current color of the clock display. Published as a hex color _with_ the leading pound sign (#)|
|`/dispbrightness`|number|0 - 255|Current brightness value of the display|
|`/autodim`|ON / OFF|OFF|Current state of the display's auto-dimming feature.|
|`/ledbrightness`|number|0 - 255|Current brightness of the LED strip. May indicate 0 when LED strip is off.|
|`/ledcolor`|String| 0,255,0|Current RGB color of the LED strip: rr,gg,bb where each value can range from 0-255.|
|`/ledstate`|String| ON or OFF|Current state of the LED strip. Always published in upper case.|
|`/temperature`|number| 71|If temperture is synced, then the last temperature value received. Value will be output in the same units as configured under the temperature integration (°C or °F). If not integrated, will show 0.|
|`/timesync`|String| 'OK' or 'FAIL'|If time is synced to an external source, indicates success of last sync.|
|`/touch1func`|String| see notes |Current primary function for Touch Sensor 1. Possible values are:<br>None, Toggle Bulb, Toggle LEDs, Bulb Brighter, Bulb Dimmer, LEDs Brighter, LEDs Dimmer, Display Brighter, Display Dimmer|
|`/touch1funca`|String| see notes |Current alarm function for Touch Sensor 1. Possible values are:<br>None, Snooze, or Stop|
|`/touch2func`|String| see notes |Current primary function for Touch Sensor 2. Same possible values as Sensor 1.|
|`/touch2funca`|String| see notes |Current alarm function for Touch Sensor 2. Same possible values as Sensor 1.|

> **💡 Alarm JSON Payloads**<br>The `/alarms` topic publishes the entire saved alarm array. It is contingent upon your external system to deserialize this JSON to utilize the values.
{: .note }

_Example payload_:
```json
[
  {
    "index": 1,
    "active": 0,
    "date": "2026-04-06",
    "time": "09:19",
    "repeat": 0
  },
  {
    "index": 2,
    "active": 0,
    "date": "2026-02-18",
    "time": "11:58",
    "repeat": 4
  },
  {
    "index": 3,
    "active": 1,
    "date": "2026-02-24",
    "time": "14:13",
    "repeat": 9
  },
  {
    "index": 4,
    "active": 1,
    "date": "2026-04-06",
    "time": "07:30",
    "repeat": 5
  },
  {
    "index": 5,
    "active": 0,
    "date": "2025-10-28",
    "time": "07:58",
    "repeat": 7
  }  
]
```
Numeric repeat values correspond to 0=None, 1=Sunday, 2=Monday. 3=Tuesday, 4=Wednesday, 5=Thursday, 6=Friday, 7=Saturday, 8=Weekends, 9=Weekdays.

---

## MQTT Command (Subscribe) Topics
The lamp is a very attentive listener. It watches these specific topics for commands; just ensure your syntax is perfect, or the lamp will politely ignore you. Commands should be published with a retain flag of **FALSE**. <br><br>Format: `cmnd/[your-subscribe-topic]/[topic-suffix]`.

|Topic Suffix|Payload(s)|Example|Notes|
|:---|:---:|:---:|:---|
|`/alarmactive`| alarm_num:active | 2:0 | Sets active state (1=on, 0=off). Values must be separated with a colon and no spaces.|
|`/alarmtrack`| number| 4|Sets alarm track index (0-20) for all alarms.|
|`/alarmupdate`| **snooze** or **stop** | snooze | Immediately snoozes or stops a sounding alarm. Ignored if idle.|
|`/alarmvolume`| number | 23 |Sets alarm volume (0-30). 0 may result in no sound.|
|`/gentlewake`| **OFF**/**ON** or **0**/**1**|ON|Enable or disable the alarm gentle wake feature.|
|`/snoozetime`| number | 10 |Sets snooze length (0 - 60 minutes). 0 disables snoozing.|
|`/playalarm`| number | 5 |Plays the current alarm track for the specified number of seconds.|
|`/setalarm`| JSON* | (See below) |Used to set or update a specific alarm slot.|
|`/bulbbrightness`|number| 128 |Sets bulb brightness. **Also toggles bulb ON if off**.|
|`/bulbcolor`| RGB or Hex String | #00ff00 | Sets bulb color. **Also toggles bulb ON if off**. Sets mode to `rgb`.|
|`/bulbtemp`| number | 250 | Sets bulb white temp (150-350). **Also toggles bulb ON if off**. Sets mode to `color_temp`.|
|`/bulbstate`|**OFF**/**ON** or **0**/**1**|ON| Sets the power state of the light bulb.|
|`/bulbrestart` | 1 | 1 | Issues a command to reboot the RGBW bulb.|
|`/clockcolor`| RGB or Hex String | #ffffff | Sets the color of the clock display (rr,gg,bb or #hex).|
|`/dispbrightness`|number| 128 | Sets display brightness (0-255). Auto-dim should be disabled first.|
|`/autodim`| **OFF**/**ON** or **0**/**1**|OFF|Enable or disable display auto-dimming.|
|`/settime`| Datetime String | 2026-04-01 14:30:00 | Sets date/time (yyyy-mm-dd hh:mm:ss). Uses 24-hour format.|
|`/settemperature`| number | 72 | Sets temperature raw value. Only applicable if weather source is MQTT or API.|
|`/ledbrightness`| number | 96 | Sets LED brightness (0-255). **Also turns LEDs ON if off**.|
|`/ledcolor`|RGB or Hex String | #60ff80 | Sets LED color. **Also turns LEDs ON if off**. #000000 appears as OFF.|
|`/ledstate`| **OFF**/**ON** or **0**/**1**|ON| Sets the power state of the LED strip.|
|`/touch1func`| number | 2 | Sets primary function for sensor 1 (Values 0-8).|
|`/touch1funca`| number | 1 | Sets alarm function for sensor 1 (Values 0-2).|
|`/touch2func`| number | 7 | Sets primary function for sensor 2 (Values 0-8).|
|`/touch2funca`| number | 2 | Sets alarm function for sensor 2 (Values 0-2).|
|`/displayrefresh`| 1 | 1 |Forces an immediate republish of all topics from the display controller.|
|`/primaryrefresh`| 1 | 1 |Forces an immediate republish of all topics from the primary controller.|
|`/refreshall`| 1 | 1 |Forces an immediate republish of all topics from **ALL** controllers.|
|`/displayrestart`| 1 | 1 | Forces an immediate reboot of the display controller.|
|`/primaryrestart`| 1 | 1 |Forces an immediate reboot of the primary controller.|
|`/restartall`| 1 | 1 | Forces an immediate restart of all THREE controllers.|
|`/dispsaveconfig`| 1 | 1 | **CAUTION:** Saves active values as new boot defaults and reboots.|
|`/primsaveconfig`| 1 | 1 | **CAUTION:** Saves active values as new boot defaults and reboots.|

> **💡 Alarm JSON Payloads**<br>To set an alarm via MQTT, you must create the alarm settings as a JSON payload.  The structure of the payload is as follows:
{: .note }

```
{
  "alarmnum": 3,
  "active": 1,
  "date": "2026-04-06",
  "time": "16:30",
  "repeat": 0
}
```

|Key|Value|Description 
|--|:---:|---
| alarmnum | 1 - 5 | Alarm “slot” number you are editing or updating 
| active | 0 or 1 | Sets alarm as inactive (0) or active (1) 
| date | date string | Alarm date. Must be in yyyy-mm-dd format 
| time | time string | Alarm time. Must be in hh:mm in 24-hour (military) format 
| repeat | 0 - 9 | Repeat setting. Valid values are:<br>0 = None<br>1 - 7 = Sunday, Monday, Tuesday…Saturday<br>8 = Weekdays<br>9 = Weekends

---

### Special MQTT Time Topic
If you opt to use MQTT time for syncing, a special independent topic is used. This allows you to leverage existing time-broadcasting automations (e.g., from Home Assistant).  See [Clock and Time]({{ '/time' | relative_url }}) for more information on setting a time MQTT topic.

<p align="center">
  MQTT Time Config
</p>

**🔍 Forcing MQTT Time Update at Boot**<br>
Since the time only updates when a new MQTT message is published, the clock could potentially show the default date and time (_January 1, 2006 12:00 am_) following the boot process and this could be shown for up to a full minute before the next MQTT message is published by the source system.

However, when MQTT time is selected as the source, the system will publish a request on a special topic during the boot process requesting an immedate time update from the source:
* **Topic:** `stat/[your-publish-topic]/gettime`
* **Payload:** `now`
* **Retain:** `false`

If you can configure the source system to listen (subscribe) to this topic and when received, publish an immediate time update, then the clock should update to the correct date/time within a few seconds after booting.

For something like Home Assistant, this would involve creating an automation that triggers on the `stat/[your-publish-topic]/gettime` topic.  When received, the automation would simply publish the current date/time to special MQTT Time Topic described above.

_This isn't a requirement.  If not possible to configure from the source, then just note that the clock may not show the correct date/time following a boot until a new MQTT message is published from the source system._

> **⚠️ Reliability Warning**<br>If using MQTT as a "live" time source and the broker or WIFI goes down, time will not be updated on the clock until the broker/WIFI is restored. This could result in missed alarms.
{: .warning }

<div style="display: flex; justify-content: space-between; align-items: center; margin-top: 40px; border-top: 1px solid #333; padding-top: 20px;">
  <a href="{{ '/integrationmain' | relative_url }}" class="btn btn-outline"><- Previous: Using MQTT and the API</a>
  <a href="{{ '/api' | relative_url }}" class="btn btn-purple">Next: API HTTP Command List -></a>
</div>

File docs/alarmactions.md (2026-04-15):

---
layout: default
title: Responding to Alarms
parent: Alarms
nav_order: 4
---

# Responding to Alarms
{: .no_toc }

---

<p align="center">
  Responding to Alarms Overview
</p>

The previous sections focused on scheduling and activation. This section covers the practical side of the system: what to do when the alarm actually sounds.

## Snoozing vs. Stopping
Regardless of which method you use to interact with the hardware, there are two primary responses to an active alarm:

* **Snooze:** Silences the alarm for the duration defined in [Alarm Options and Settings]({{ '/alarmoptions' | relative_url }}). Once the timer expires, the alarm sounds again.
* **Stop:** Permanently cancels the current alarm event. If the alarm is set to repeat (e.g., every Wednesday), it will not sound again until the next scheduled occurrence. At this point, the lamp has done its job; the rest is up to you. (I recommend coffee.)

> **💡 Minimum Snooze Requirement**<br>The snooze period must be set to at least **one minute** for these features to function. If your snooze time is set to 0, all snooze-related buttons and functions are disabled.
{: .note }

---

## Method 1: Using the Touch Display
When an alarm sounds, the screen automatically brightens to its **DEFAULT** brightness (if it was previously dimmed). The clock face is updated with dedicated **SNOOZE** and **STOP** buttons.

<p align="center">
  Touch Display Alarm Interface
</p>

* **To Snooze:** Tap the SNOOZE button. The alarm will stop and the display will keep the STOP button visible in case you decide to cancel the alarm before the snooze expires.
<p align="center">
  Display during Snooze
</p>

* **To Stop:** Tap the STOP button at any time to cancel the alarm and return the system to normal clock mode.

---

## Method 2: Using the Touch Sensors
If you have [configured your touch sensors]({{ '/touchsensors' | relative_url }}) with "Snooze" and "Stop" as their Alarm Functions, you can respond to the alarm simply by tapping the top of the lamp enclosure.

<p align="center">
  Touch Sensor Usage
</p>

The behavior on the screen remains the same as the touch display method, but there is one critical operational difference during a snooze:

> **⚠️ Sensor Function Reversion**<br>While the alarm is in a **Snooze** state, the touch sensors immediately revert to their **Primary Function** (e.g., toggling the LED strip or light bulb). You **cannot** use the touch sensors to cancel a snoozed alarm early; you must use the touch display or a web command to cancel the alarm before the snooze timer expires.
{: .important }

---

## Method 3: Using External Systems
For those utilizing smart home hubs or other external systems like Home Assistant, you can snooze or stop alarms via the network.  See [Using MQTT and the API](/integrationmain.md) for complete details.

### MQTT
Send a command to the `alarmupdate` topic:
* **Topic:** `cmnd/[your-mqtt-topic]/alarmupdate`
* **Payload:** `snooze` or `stop`

### HTTP API
Post a direct URL to the controller's IP address:
* **Snooze:** `http://[IP]/api?alarmupdate=snooze`
* **Stop:** `http://[IP]/api?alarmupdate=stop`

The results are identical to a physical tap—the hardware will react, and the touch display will update its state accordingly.

---

<div style="display: flex; justify-content: space-between; align-items: center; margin-top: 40px; border-top: 1px solid #333; padding-top: 20px;">
  <a href="{{ '/alarms' | relative_url }}" class="btn btn-outline"><- Previous: Setting and Editing Alarms</a>
  <a href="{{ '/integrationmain' | relative_url }}" class="btn btn-purple">Next: Using MQTT and the API -></a>
</div>

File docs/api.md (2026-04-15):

---
layout: default
title: API HTTP Command List
parent: Using MQTT and the API
nav_order: 2
---

# HTTP API Command List
{: .no_toc }

---

<p align="center">
  HTTP API Overview
</p>

The API allows for "headless" control of the system via simple HTTP requests. It's essentially a remote control that lives in your browser's address bar or your favorite automation script. Unlike MQTT, the API does not require third-party intermediaries (like a broker) or complex configuration. Commands are issued as standard URLs:

`http://[your-controller-ip]/api?...`

> **💡 IP Routing**<br>For most commands, you can use either the Primary or Display controller's IP address; the firmware handles internal routing automatically. Only the **PING** command must be sent to a specific controller's IP to verify that specific unit.
{: .note }

### Command Chaining
Some commands can be combined into a single HTTP call by concatenating them with an ampersand (`&`). 

**Example:**
`http://[primary-ip-address]/api?ledbrightness=128&ledcolor=ff0000`

Other commands must be sent as the only command in the URL.   

---

### SET Commands
These commands are used to modify the active state of the system. Commands marked **NO** in the "Multi" column must be sent as standalone requests and cannot be combined with other commands.

| Command | Parameter(s) | Returns | Multi | Example / Notes |
| :--- | :---: | :---: | :---: | :--- |
| `alarmactive` | alarmnum&active=n | OK | **NO** | `/api?alarmactive=2&active=1`<br>Sets active state of specified alarm. |
| `alarmtrack` | number (1-20) | OK | Yes | `/api?alarmtrack=13`<br>Sets the active track for alarm sound. |
| `alarmupdate` | snooze *or* stop | OK | Yes | `/api?alarmupdate=snooze`<br>Snoozes/stops alarm (Ignored if idle). |
| `alarmvolume` | number (0-30) | OK | Yes | `/api?alarmvolume=15`<br>Sets alarm volume (or max for Gentle Wake). |
| `snoozetime` | number (0-60) | OK | Yes | `/api?snoozetime=10`<br>Sets snooze time in minutes. |
| `playalarm` | length (0-60) | OK | Yes | `/api?playalarm=15`<br>Plays current alarm track for X seconds. |
| `setalarm` | *See notes below* | OK | **NO** | Must be the only command sent. |
| `bulbbrightness`| number (0-255) | OK | Yes | `/api?bulbbrightness=128`<br>Sets brightness; toggles bulb ON. |
| `bulbcolor` | RGB *or* Hex | OK | Yes | `/api?bulbcolor=00ff00`<br>Sets color and mode to [rgb]; toggles ON. |
| `bulbstate` | OFF / ON (0/1) | OK | Yes | `/api?bulbstate=ON`<br>Sets bulb power state. |
| `ledbrightness`| number (0-255) | OK | Yes | `/api?ledbrightness=128`<br>Sets LED brightness; toggles strip ON. |
| `ledcolor` | RGB *or* Hex | OK | Yes | `/api?ledcolor=ff00ff`<br>Sets LED color (omit '#'); toggles ON. |
| `ledstate` | OFF / ON (0/1) | OK | Yes | `/api?ledstate=ON`<br>Sets LED strip power state. |
| `clockcolor` | RGB *or* Hex | OK | Yes | `/api?clockcolor=ffffff`<br>Sets color of the clock display (omit '#'). |
| `dispbrightness`| 0-255, up, down | OK | Yes | `/api?dispbrightness=up`<br>Adjusts brightness. *Auto-dim must be OFF.* |
| `autodim` | OFF / ON (0/1) | OK | Yes | `/api?autodim=OFF`<br>Sets the display's auto-dimming state. |
| `settemperature`| number | OK | Yes | `/api?settemperature=72`<br>Source must be MQTT/API. Raw value. |
| `settime` | *See notes below* | OK | **NO** | Applicable only if time source is Manual. |
| `touch1func` | number (0-8) | OK | Yes | `/api?touch1func=1`<br>Sets Sensor 1 primary function (0-8). |
| `touch1funca` | number (0-2) | OK | Yes | `/api?touch1funca=2`<br>Sets Sensor 1 alarm function (0-2). |
| `touch2func` | number (0-8) | OK | Yes | `/api?touch2func=1`<br>Sets Sensor 2 primary function. |
| `touch2funca` | number (0-2) | OK | Yes | `/api?touch2funca=2`<br>Sets Sensor 2 alarm function. |
| `bulbrestart` | 1 | OK | **NO** | `/api?bulbrestart=1`<br>Restarts the RGBW Light bulb. |
| `displayrestart`| 1 | OK | **NO** | `/api?displayrestart=1`<br>Restarts the display controller. |
| `primaryrestart`| 1 | OK | **NO** | `/api?primaryrestart=1`<br>Restarts the primary controller. |
| `restartall` | 1 | OK | **NO** | `/api?restartall=1`<br>Restarts all three controllers. |
| `dispsaveconfig`| 1 | OK | **NO** | **CAUTION:** Saves active as default and reboots. |
| `primsaveconfig`| 1 | OK | **NO** | **CAUTION:** Saves active as default and reboots. |

### Detailed SET Parameter Notes

**Setting an Alarm**<br>
Requires a specific set of parameters: `/api?setalarm=1&alarmnum=3&date=2026-04-01&time=14:30:00&repeat=7`
* **setalarm**: `0` (Inactive) or `1` (Active).
* **alarmnum**: Slot `1-5`.
* **date**: `YYYY-MM-DD`.
* **time**: `hh:mm:ss` (Seconds required, 24-hour format).
* **repeat**: `0-9` (0=None, 1-7=Days, 8=Weekdays, 9=Weekends).

**Setting the Time**<br>
Requires: `/api?settime=1&mon=4&day=15&yr=2026&hr=14&min=30&sec=0`
* **Source**: Time source must be set to **Manual** for this to persist. Otherwise the next sync will overwrite the set time.
* **Requirements**: All parameters (Month, Day, Year, Hour, Minute, Second) are required. Hours must be specified in 24-hour (military) format.

---

### GET Commands
These commands retrieve data and do not modify settings. They must be sent individually.

| Command | Parameter(s) | Returns | Example / Notes |
| :--- | :---: | :---: | :--- |
| `ping` | 1 | OK | `/api?ping=1`<br>Send to the specific controller IP. |
| `primaryipaddr` | 1 | IP Address | Returns IP of primary controller. |
| `displayipaddr` | 1 | IP Address | Returns IP of display controller. |
| `bulbipaddr` | 1 | IP Address | Returns IP of RGBW light bulb. |
| `primarymac` | 1 | MAC Address | Returns MAC of primary controller. |
| `displaymac` | 1 | MAC Address | Returns MAC of display controller. |

---

## DIRECT Commands
These are shortcut commands typically sent to a specific controller. Note the **omission** of `/api` in the URL.

### Controller-Specific Direct Calls

| Command | Parameter(s) | Returns | Notes |
|---|:---:|:---:|---|
| `/restart` | none | Web Page | Reboots the targeted controller. |
| `/restartall` | none | Web Page | Reboots all three units (Primary IP only). |
| `/otaupdate` | none | Web Page | Places targeted unit in OTA Update mode. |

### RGBW Light Bulb Direct Commands
The bulb uses the ESPHome API base: `http://[bulb-ip]/light/[bulbname]/[command]`

| Command | Parameter(s) | Returns | Notes |
|---|:---:|:---:|----|
| *empty* | none | JSON | Returns a JSON payload of current state. |
| `/turn_on` | optional | OK | Toggles bulb on with last or new settings. |
| `/turn_off` | none | OK | Turns the light bulb off. |

**💡 JSON Example: Current Bulb State**
```json
{
  "id": "light-bedside_lamp_bulb",
  "state": "ON",
  "color_mode": "color_temp",
  "brightness": 198,
  "color_temp": 287
}
```
**🔍 JSON Payload May Vary**<br>The contents of the bulb's state payload will vary based on whether the bulb is in _color_temp_ or _rgb_ color mode.
{: .note }

---

## External Bulb Support

While not utilitized or linked to from the app, the bulb does have its own web interface that can be accessed by simply entering the bulb's IP address in a browser.

<p align="center">
  Bulb Web Interface
</p>

> **❗ Support Disclaimer**<br>The Kauf bulb utilizes its own factory ESPHome firmware. This project makes use of the provided API but does not maintain the bulb's internal firmware. For assistance with the bulb itself, refer to the [Kauf Common Repository](https://github.com/KaufHA/common) or the [Kauf RGBWW Bulb Repository](https://github.com/KaufHA/kauf-rgbww-bulbs).
{: .important }

<div style="display: flex; justify-content: space-between; align-items: center; margin-top: 40px; border-top: 1px solid #333; padding-top: 20px;">
  <a href="{{ '/mqtt' | relative_url }}" class="btn btn-outline"><- Previous: MQTT Setup & Topics</a>
  <a href="{{ '/discoverymain' | relative_url }}" class="btn btn-purple">Next: Home Assistant Discovery -></a>
</div>

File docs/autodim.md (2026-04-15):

---
layout: default
title: Auto-Dimming
parent: Setting Up the System
nav_order: 3
---

# Auto-Dimming
{: .no_toc }

---

<p align="center">
  Auto-Dimming Overview
</p>

The display can be configured to automatically adjust its brightness based on the measured ambient light in the room. Unlike many retail clocks with fixed dimming, this system allows you to define a custom curve by specifying exact ambient light percentages and their corresponding display brightness levels.

<p align="center">
  Dimmed Display Example
</p>

### Setting Up Auto-Dimming
To configure these settings, return to the **Display Settings** page via the web application. The auto-dim options are located on the lower half of the page.

Navigation to Auto-Dim

  autodim_03

These options define the **DEFAULT** values loaded at boot. You can temporarily override these settings during operation, as covered in [Managing Display Brightness]({{ '/dispbrightness' | relative_url }}).

### Core Settings
* **Enable Auto-Dimming:** Check this box to activate the feature by default. If unchecked, brightness remains constant at the "Default Brightness" level.
* **Auto-Dim Debounce:** Specifies a delay (0–10 seconds) before a brightness change is applied. 
    > **💡 Performance Hint**<br>Debouncing prevents the display from flickering if a shadow passes over the sensor or a light reflects off the screen. A value of **2–5 seconds** is recommended for a smooth experience.
    {: .note }

### Ambient Light and Brightness Logic
The system uses a tiered logic to determine brightness. You can specify up to four ambient light thresholds and five brightness levels. 

> **💡 Understanding the Curve**<br>The system evaluates the room brightness from **Highest to Lowest**:
> * If the light is **above** your top threshold (e.g., 50%), the highest brightness (e.g., 94%) is used.
> * If the light falls **between** two thresholds, the lower corresponding brightness is applied.
> * If the light is **below** your minimum threshold (e.g., 5%), the lowest defined brightness is used.
{: .note }

<p align="center">
  Brightness Logic Table
</p>

---

## Calibration Mode
Because "50% brightness" looks different in every room, the system includes a live calibration tool. 

> **⚠️ Warning**<br>Clicking the **Calibrate** button will discard any unsaved values currently entered on the Auto-Dim settings page.
{: .warning }

<p align="center">
  Calibration Interface
</p>

The calibration page provides a "Live" ambient light reading that updates once per second. To find your ideal settings:
1. Adjust your room lighting (turn on lamps, close curtains, etc.).
2. Observe the measured ambient level.
3. Use the slider to find a display brightness that feels comfortable for that specific light level.
4. **Jot down these pairs** (Ambient % and Display %); they are not saved automatically on this page.

**Note:** The calibration page is a sandbox. Use it to determine your desired values, then return to the Auto-Dim settings page to enter and save them.

>🔍 **The Brightness Balancing Act**<br>Finding the perfect auto-dimming levels is a bit of an art form. You want it bright enough to read during a sunny afternoon, but not so bright that it feels like the sun has decided to move into your bedroom at 3:00 AM. If you find your lamp is constantly flickering between brightness levels, you’ve likely set your thresholds too close together—give the sensor a little breathing room!
{: .note }

---

### Maintenance Actions
* **RESET Button:** Restores all values to the last saved defaults, overwriting any unsaved changes.
* **SAVE AND REBOOT:** Commits your new curve to the configuration file and restarts the controller to apply them as the new system defaults.

---

<div style="display: flex; justify-content: space-between; align-items: center; margin-top: 40px; border-top: 1px solid #333; padding-top: 20px;">
  <a href="{{ '/display' | relative_url }}" class="btn btn-outline"><- Previous: Display Configuration</a>
  <a href="{{ '/lights' | relative_url }}" class="btn btn-purple">Next: Light Settings -></a>
</div>

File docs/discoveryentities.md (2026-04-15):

---
layout: default
title: Editing or Hiding Discovered Entities
parent: Home Assistant Discovery
nav_order: 2
---

# Editing or Hiding Discovered Entities
{: .no_toc }

---

<p align="center">
  [PLACEHOLDER: Editing and Entity Reference]
</p>

One of the most powerful features of the Discovery system is the ability to choose exactly which components of the lamp are exposed to Home Assistant. You can add or remove groups of entities at any time to keep your dashboard clean and relevant.

---

## Updating an Existing Discovery
The primary controller stores your previous settings in a `discovery.json` file. This allows you to modify your entity list without creating duplicates in Home Assistant.

### Modifying Entity Groups
1. Navigate to the **Discovery** page in the **Advanced** menu.
2. Your previously selected groups will be pre-populated.
3. Check any additional groups you wish to add, or uncheck groups you wish to remove.
4. Click the **UPDATE DISCOVERY** button.

> **💡 Device Name Limitation**<br>The **Device Name** is used to generate unique MQTT discovery topics. Because of this, you cannot change the Device Name once Discovery is enabled. To change the name, you must first [Remove Discovery]({{ '/discoverymanage' | relative_url }}) and then recreate it with the new name.
{: .note }

### The Update Button
When you click **UPDATE DISCOVERY**, the system immediately sends "clearance" messages for any removed groups and "discovery" messages for any new ones. 

> **⚠️ Dashboard Warning**<br>If you remove an entity group that is currently in use on a Home Assistant dashboard or in an automation, those items will show as "Unavailable" or may break entirely.
{: .warning }

---

## Handling System Resets or Hardware Changes
Because Discovery relies on a unique string (Device Name + MAC Address), certain hardware events require attention:

* **System Reset (Same ESP32):** If you perform a factory reset but use the same hardware and the same Device Name, running Discovery again will simply "take over" the existing entities in Home Assistant.
* **New ESP32 / Different Name:** If you replace the controller or change the name, Home Assistant will treat it as a brand-new device. In this case, it is best to delete the old device from the Home Assistant **Devices** page to avoid clutter.

## Entities Created Reference Table
The following table lists the entities created in Home Assistant based on your selections. 

*Note: `device_name` refers to your specified Discovery Device Name (converted to lowercase with underscores).*

| Entity Group | Entities Created | Friendly Name |
| :--- | :--- | :--- |
| **RGBW Light Bulb** | `light.device_name_bulbstate`<br>*(Includes brightness, color & temperature attibutes)* | Light Bulb |
| **LED Strip** | `light.device_name_ledstate`<br>*(Includes brightness and color attributes)* | LED Strip |
| **TFT Display** | `number.device_name_dispbrightness`<br>`switch.device_name_autodim`<br>`text.device_name_clockcolor` | Display Brightness<br>Auto-Dimming<br>Clock Color |
| **Touch Sensors** | `binary_sensor.device_name_touch1state`<br>`binary_sensor.device_name_touch2state`<br>`select.device_name_touch1func`<br>`select.device_name_touch2func` | Touch 1 State<br>Touch 2 State<br>Touch 1 Main Function<br>Touch 2 Main Function |
| **Alarms** | `number.device_name_alarmvolume`<br>`number.device_name_alarmtrack`<br>`number.device_name_snoozetime`<br>`switch.device_name_gentlewake`<br>`button.device_name_alarm_snooze`<br>`button.device_name_alarm_stop` | Alarm Volume<br>Alarm Track<br>Snooze Duration<br>Gentle Wake<br>Snooze Alarm<br>Stop Alarm |
| **Diagnostics** | `sensor.device_name_ip_display`<br>`sensor.device_name_ip_bulb`<br>`sensor.device_name_ip_primary`<br>`button.device_name_rb_display`<br>`button.device_name_rb_primary` | IP Addr Display<br>IP Addr Light Bulb<br>IP Addr Primary<br>Restart Display<br>Restart Primary |

> **💡 Customization**<br>You can safely rename these entities or change their icons directly within the Home Assistant UI without affecting the lamp's firmware.
{: .note }

---

<div style="display: flex; justify-content: space-between; align-items: center; margin-top: 40px; border-top: 1px solid #333; padding-top: 20px;">
  <a href="{{ '/discoverymanage' | relative_url }}" class="btn btn-outline"><- Previous: Enabling and Disabling Discovery</a>
  <a href="{{ '/discoverymanual' | relative_url }}" class="btn btn-purple">Next: Manually Creating MQTT Entities -></a>
</div>

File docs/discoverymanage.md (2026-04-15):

---
layout: default
title: Enabling and Disabling Discovery
parent: Home Assistant Discovery
nav_order: 1
---

# Enabling and Disabling Discovery
{: .no_toc }

---

<p align="center">
  [PLACEHOLDER: Enabling/Disabling Discovery]
</p>

Once your MQTT broker is verified and your Device Name is chosen, you are ready to initiate the Discovery process. This establishes the initial link between your lamp and Home Assistant.

---

## Accessing the Discovery Menu
The Discovery settings are located within the **Advanced** menu of the primary controller.

1. From the main web application, click the **Advanced** button.
2. Scroll down to the section located under the **Touch Control Settings**.

Discovery Settings Location

## Enabling Discovery
Before clicking the enable button, confirm your configuration:

* **Device Name:** Ensure the name is 1-32 characters and correctly formatted (alphanumeric and spaces only).
   * Recall that the device name will be assigned to the created device in Home Assistant _and_ will be prepended to all entity names.  This is a Home Assistant _"feature"_ and a not function of the firmware.
* **Entity Groups:** Check the boxes for the groups you wish to export to Home Assistant. You can always add more later.
> **💡 Entity Group Selection**<br>It is not required that all entity groups be selected.  You can choose which entity groups you want included in the Home Assistant device.
{: .note }

discoverymain_07

If the above selections are made, then in Home Assistant just the entities related to the light bulb and LED strip will be generated.

discoverymain_08

### The Enablement Process
Click the **ENABLE DISCOVERY** button. You will be prompted with a final confirmation dialog. 

> **💡 Instant Integration**<br>There is no prompt or "accept" button within Home Assistant itself. As soon as you confirm in the lamp's web app, the device is broadcast to the broker and Home Assistant will immediately add the new device and entities.
{: .note }

Discovery Confirmation

Once confirmed, you can navigate to the **Devices & Services** section in Home Assistant to verify the "Bedside Lamp" (or your custom name) is listed.

---

## Removing or Disabling Discovery
If you need to completely remove the lamp from your Home Assistant environment, do not simply delete it from the HA dashboard.

> **⚠️ Proper Removal Procedure**<br>If you simply delete the device directly within Home Assistant, it may spontaneously reappear the next time the lamp or the HA server restarts. To permanently remove the integration, use the **REMOVE DISCOVERY** button on the lamp’s Discovery page.
{: .warning }

Removing Discovery

Clicking **REMOVE DISCOVERY** sends a "clearance" message to the MQTT broker, ensuring all discovery topics are purged and the device is cleanly unlinked from Home Assistant.  If you end up with orphaned entities or ones that continue to reappear in Home Assistant, see the [Troublshooting](/troubleshooting.md) topics.

<div style="display: flex; justify-content: space-between; align-items: center; margin-top: 40px; border-top: 1px solid #333; padding-top: 20px;">
  <a href="{{ '/discoverymain' | relative_url }}" class="btn btn-outline"><- Previous: Home Assistant Discovery</a>
  <a href="{{ '/discoveryentities' | relative_url }}" class="btn btn-purple">Next: Editing or Hiding Entities -></a>
</div>

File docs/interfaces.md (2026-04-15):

---
layout: default
title: Setting up the System Interfaces
parent: Getting Started
nav_order: 3
has_toc: false
---

# Setting up the System Interfaces
{: .no_toc }

---

<p align="center">
  System Interfaces Header
</p>

As discussed in the [Concepts and Terminology]({{ '/concepts' | relative_url }}) section, this system operates as a "triumvirate" of three ESP-based controllers. 

02Overall_1_Truimvirate

Because these controllers are not physically wired together, they must communicate wirelessly over your local network using a custom internal API. For this to succeed, each controller must be configured with the IP addresses of its counterparts.

**📋 Pre-Flight Check**<br>Before proceeding, ensure you have completed the [Onboarding]({{ '/onboarding' | relative_url }}) for all three devices (Bulb, Primary, and Display) and that you have assigned them **Static or Reserved IP addresses** in your router.
{: .note }

---

## Accessing the Web Application

To configure the interfaces, you will use the system's built-in web application hosted on the **Primary Controller**.

1. Power on all three devices.
2. Ensure your computer or phone is on the same Wi-Fi network.
3. Open a browser and enter the IP address of the **Primary Controller** (e.g., `http://192.168.1.205`).

05System_03_Main

On the main page, navigate to the **Settings and Defaults** section and click the **System** button.

### ⏳ A Note on Automated Verification
When you open the System Settings page, the firmware automatically tests every interface by issuing a command and waiting for a response. 

**All fields will be disabled and show "Loading..." during this test.** Please be patient and do not refresh the page; the fields will become active once the tests are complete (displaying status messages like *Enabled & Connected* or *Not Connected*).

05System_03b_Main

---

## Primary Controller Configuration

### Boot Delay (Optional)
This setting impacts how the Primary Controller initializes during a cold boot. 

05System_03c_Integrations

By default, this is set to **0 seconds**. If your Wi-Fi network is slow to initialize and the controllers fail to "find" each other during power-up, you can increase this delay. If you aren't experiencing boot issues, leave this at 0.

### Core Integrations

**⚠️ IP Addresses: Get the Numbers Right**<br>This is the part where you play matchmaker. You’ll need to tell the Primary Controller exactly where its siblings live on the network. Be precise! If you typo an IP address here, the controllers will spend their lives shouting into the void, wondering why nobody is returning their calls. It’s a classic case of digital "it’s not you, it’s my configuration."
{: .important }

For the initial setup, you must complete the following three sections:

05System_04_Integrations

1.  **LED Light Strip:** Enter the total number of LEDs used in your build. 
    * This allows the firmware to calculate proper power distribution and color flow. 
    * If the exact number is unknown at this point, just enter an approximation (say 15-20) and we'll fine-tune it later.
2.  **Main Light Bulb:**
    * Enter the bulb's **IP Address**.
    * Enter the **Bulb Name** in "Home Assistant Entity" format (lowercase, underscores instead of spaces).
3.  **Touch Panel Display:** Enter the **IP Address** of the Display (Secondary) Controller.

**🌐 Optional Features**<br>Other settings on this page, such as **MQTT** and **Weather Integrations**, require external connections or internet access. These are entirely optional and should only be configured after you have confirmed the core "triumvirate" is working.
{: .note }

### Save and Reboot
Once the three sections above are filled, scroll to the bottom and click **Save and Reboot**.

05System_04_Save

The system will restart. You may notice "boot indicators" such as the LED strip or bulb flashing RGB colors. This is normal and is detailed in [The Boot Process]({{ '/booting' | relative_url }}) documentation.

**🔍 Dual Rebooting**<br>Depending upon the specific operation, a reboot of the primary controller may also require a reboot of the display controller.  The system handles this automatically when needed.
{: .important }

## Display Controller Configuration

The Primary Controller now knows how to find the Display Controller, but we must now tell the Display how to find the Primary.

### 1. Identify the Interface
Launch the web app again by navigating to the Primary Controller's IP. This time, select **Display** under Settings and Defaults.

05System_05_Display

**How to tell which controller you are viewing:**
* **Primary Controller:** Light Gray background. Device name also shown at the top and in the browser tab.
* **Display Controller:** Pale Yellow background. Device name also shown at the top and in the browser tab.

### 2. Enter Primary IP
From the Display interface (Yellow background), click **System**.

05System_06_DisplaySystem

Locate the integration field and enter the **IP Address of the Primary Controller**.

05System_06_DispIntegration

### 3. Save and Reboot
Scroll to the bottom and click **Save and Reboot**. The Display controller will restart and attempt to link with the Primary. You can monitor the physical screen on the device to verify a successful connection.

---

With these steps completed, your "Controller Triumvirate" is now fully linked. Once the system successfully completes the boot process, you can return to the web application to customize your preferences or set up optional services.

<div style="display: flex; justify-content: space-between; align-items: center; margin-top: 40px; border-top: 1px solid #333; padding-top: 20px;">
  <a href="{{ '/onboarding' | relative_url }}" class="btn btn-outline"><- Previous: Onboarding</a>
  <a href="{{ '/booting' | relative_url }}" class="btn btn-purple">Next: The Boot Process -></a>
</div>

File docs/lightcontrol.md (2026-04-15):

---
layout: default
title: Controlling Lights
parent: General System Use
nav_order: 1
---

# Controlling the Lights
{: .no_toc }

---

<p align="center">
  Lighting Control Header
</p>

This section covers the various methods for controlling the main RGBW light bulb and the LED strip. 

> **💡 Reminder: Active Settings**<br>Most interactions described here only update the **ACTIVE** settings. This means any changes to colors or brightness will be lost and the hardware will revert to its **DEFAULT** boot settings if the system is restarted or power is lost.
{: .note }

---

## Control via the Web Application
The web application offers the most granular control over your lighting. The controls are located at the top of the primary controller’s main page.

Web App Lighting Controls

### Color Selection
Clicking the color box for either light opens the color picker. 

Color Picker Interface

* **Visual Selection:** Use the slider for the hue and the large box for saturation/value.
* **Eyedropper:** Select any color visible on your desktop.
* **Manual Input:** Enter RGB, HSL, or Hex codes. 
   * **Auto-Mode Switch (bulb only):** Note that selecting a color automatically switches the light bulb to **RGB Mode**.

### Core Controls
* **State Buttons:** Toggle the power for either the bulb or the strip. 
* **Brightness Sliders:** Represented by the "sun" icon. Move to the right to increase intensity. The value is sent to the hardware as soon as you release the slider.
* **White Temperature (Bulb Only):** Indicated by the thermometer icon. Sliding to the left creates a "Cool" blue-white; sliding to the right creates a "Warm" yellow-white.
    * **Auto-Mode Switch:** Adjusting this automatically switches the bulb to "White/Color Temp Mode." The color picker box will turn white to reflect this state.

> **⚠️ Performance Note**<br>The ESP32 processes web requests alongside all other system functions. You may notice a slight delay (1–2 seconds) between clicking a button and seeing the interface update. Avoid rapid "multi-clicking" to prevent queuing up conflicting commands.
{: .warning }

### Refresh & Sync
The web server only sends data in response to a request. If you change the lights via MQTT or the touch display while the web app is open, the browser won't know. Click the **REFRESH & SYNC** link to force the web app to pull the current "Active" values from the hardware.

---

## Control via the Touch Display
If touch is enabled, you can toggle the power states directly from the clock's display.

1. Tap the **Gear Icon** (⚙) in the upper right corner of the clock display.
2. Tap the **Bulb** or **LED** button to toggle the state.

Touch Display Settings

> **💡 Note: State Only**<br>The touch display only toggles the On/Off state. The lights will turn on using whatever **ACTIVE** color, brightness, and temperature are currently in effect. To change colors or brightness, use the web app or external commands.
{: .note }

*The settings menu will automatically exit and return to the clock after 10 seconds of inactivity, or you can tap the red **X**.*

---

## Control from External Sources
Advanced users can integrate the lamp into systems like Home Assistant via MQTT or the HTTP API.

***MQTT***<br>
Commands are sent to the `cmnd/` topic. Examples include:
* **Set LED State:** `cmnd/[topic]/ledstate` (Payload: `on`, `off`, `0`, or `1`)
* **Set LED Brightness:** `cmnd/[topic]/ledbrightness` (Payload: `0-255`)
* **Set LED Color:** `cmnd/[topic]/ledcolor` (Payload: `255,0,0` or `#ff0000`)

See [MQTT Setup and Topics]({{ '/mqtt' | relative_url }}) for the full list of available topics.

***HTTP API***<br>
The API is accessible via standard URL posts to the controller’s IP address:
* **Set Bulb State:** `http://[IP]/api?bulbstate=on`
* **Set Bulb Brightness:** `http://[IP]/api?bulbbrightness=96`
* **Set Bulb Color:** `http://[IP]/api?bulbcolor=ff0000`
* **Set Bulb Temp:** `http://[IP]/api?bulbtemp=225`

See the [API HTTP Command List]({{ '/api' | relative_url }}) for details.

<div style="display: flex; justify-content: space-between; align-items: center; margin-top: 40px; border-top: 1px solid #333; padding-top: 20px;">
  <a href="{{ '/usingmain' | relative_url }}" class="btn btn-outline"><- Previous: General System Use</a>
  <a href="{{ '/dispbrightness' | relative_url }}" class="btn btn-purple">Next: Managing Display Brightness -></a>
</div>

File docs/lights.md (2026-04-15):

---
layout: default
title: Lights
parent: Setting Up the System
nav_order: 4
---

# Light Bulb and LED Strip Settings
{: .no_toc }

---

<p align="center">
  Lighting Configuration Header
</p>

To access the default configurations for the RGBW Light Bulb and the LED Strip, select the **Lights** option from the primary controller’s main menu.

Lighting Menu Access

The configuration page is divided into two distinct sections: the **LED Strip** settings at the top and the **Main Light Bulb** settings at the bottom. 

> **💡 Reminder**<br>These settings define the **DEFAULT** boot state. Changes made here will only take effect after a reboot and do not immediately alter the **ACTIVE** state of the lights. For more on this distinction, see the [Web App Overview]({{ '/webapp' | relative_url }}).
{: .note }

---

### LED Strip Configuration

LED Strip Settings

* **Total Number of LEDs:** Use this field to fine-tune your strip length. If you are using a COB strip or a custom length, enter an estimate and use the **TEST** button. Adjust the number until the very last pixel is lit, but no further.
* **Start-up State:** Determines if the strip is ON or OFF immediately following a boot.
* **Default Color:** The color applied at boot. Clicking the color box opens a full color picker supporting RGB, HSL, and Hex values.
* **Default Brightness:** Sets the initial intensity (0-100%). 
    > **💡 Tech Tip**<br>Some high-density LED strips may not illuminate at extremely low percentages (1-3%). If the strip appears "dead" while toggled ON, try increasing the default brightness to 5-10% and re-test.
    {: .note }
* **Show Test During Boot:** If enabled, the strip will flash Red, Green, and Blue during the startup sequence to verify hardware integrity. After booting the LEDs will be set to the specified Start-up state.
* **TEST / STOP:** Toggles the strip on with current screen values to verify the LED count or color.

---

### Main Light Bulb Settings

Bulb Settings

The smart bulb configuration works similarly to the LED strip but includes options for the dedicated white channel.

* **Bulb IP & Name:** Informational fields. To modify these network identifiers, visit the [System Interfaces]({{ '/interfaces' | relative_url }}) page.
* **Start-up State:** Determines if the bulb defaults to ON or OFF after booting.
* **Default Color Mode:** Choose between **RGB** (Color) or **White** (Temperature).
* **Default RGB Color:** Operates identically to the LED strip color picker above. This color is used when the bulb is in RGB mode.
* **Default White Temperature:** Adjusts the "warmth" of the white light when in White mode.
    * **Cool White:** ~6,600 K (150 mired).
    * **Warm White:** ~2,800 K (350 mired).
* **Default Brightness:** Sets the initial bulb intensity. Some bulbs may not illuminate at very low settings.
* **Show Test During Boot:** Flashes the bulb Red, Green, and Blue during the primary controller boot process. After booting completes, the bulb is set to the specified Start-up state.

---

### Managing Changes

> **⚠️ Important: Button Independence**<br>The LED Strip and the Light Bulb sections operate **independently**. Each has its own set of Test, Reset, and Save buttons. 
> * Clicking "Save and Reboot" in the Bulb section **will not** save pending changes made in the LED section above it, and vice versa
> * You must save (and reboot) each section independently.  Otherwise changes in the opposite section will be lost
{: .important }

* **TEST:** Toggles the hardware on with your current *unsaved* screen values.
* **RESET:** Reverts all fields in that section to the last saved defaults.
* **SAVE AND REBOOT:** Commits the values for that specific section to flash memory and restarts the controller to apply them.

<div style="display: flex; justify-content: space-between; align-items: center; margin-top: 40px; border-top: 1px solid #333; padding-top: 20px;">
  <a href="{{ '/autodim' | relative_url }}" class="btn btn-outline"><- Previous: Auto-Dim Settings</a>
  <a href="{{ '/time' | relative_url }}" class="btn btn-purple">Next: Clock and Time Settings-></a>
</div>

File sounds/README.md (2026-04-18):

## Sound Readme
This folder contains various sounds you can download and use as potential alarm sounds by copying to your microSD card.  Information on preparing the SD card and how to add or substitute your own MP3 files as alarm sounds, see the [Build Guide](https://resinchemtech.blogspot.com/2026/04/ultimate-bedside-lamp.html) and the [Setting Up Alarm Sounds](https://resinchem.github.io/Ultimate-Bedside-Lamp/sounds.html) topic of the firmware guide. 

|File Name| Track Title |Type|&nbsp;\|&nbsp;|File Name| Track Title | Type
|---|---|----|:--:|--|--|--
|0001.mp3|Piano Sonata|Musical|\||0010.mp3|FX - Beeps |Sound Effect
|0002.mp3|Cool Vibes|Musical|\||0011.mp3|FX - Low Buzz |Sound Effect
|0003.mp3|Gentle Waves|Musical|\||0012.mp3|FX - BeBop |Sound Effect
|0004.mp3|Rise and Shine |Musical|\||0013.mp3|FX - Red Alert |Sound Effect
|0005.mp3|Jazzy Start |Musical|\||0014.mp3|FX - Buzzer |Sound Effect
|0006.mp3|Foggy Mountain |Musical|\||0015.mp3|FX - High Low |Sound Effect
|0007.mp3|Jazz Me Up |Musical|\||0016.mp3|FX - Rising Bell |Sound Effect
|0008.mp3|Lullaby |Musical|\||0017.mp3|FX - Rooster |Sound Effect
|0009.mp3|Xylophone Notes |Musical|\||0018.mp3|FX - Two Beeps |Sound Effect

_Track title is arbitrary.  You can change this in the web app sound library_

Up to 255 audio files can be transferred to the microSD card, but only the first 20 files (_by physical location_) can be used as an alarm sound.

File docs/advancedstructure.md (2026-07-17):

---
layout: default
title: Firmware and File Structure
parent: Advanced Technical Information
nav_order: 1
---

# Firmware and File Structure
{: .no_toc }

---

<p align="center">
  [PLACEHOLDER: Firmware and File Structure]
</p>

As detailed in the [Concepts and Terminology]({{ '/concepts' | relative_url }}) section, this system distributed its logic across three different ESP-based controllers. Understanding how these files are structured is essential for anyone looking to compile the source code or verify their installation.

<p align="center">
  The Three Controllers Architecture
</p>

---

### 1. Kauf RGBW Light Bulb
The light bulb arrives from the factory with a specialized version of **ESPHome** firmware. This project is built specifically to interface with that factory firmware.

* **Compatibility:** This system was developed and tested using Kauf firmware version **1.962(y)** with ESPHome **2025.9.2**. 
* **Modifications:** If you replace this firmware (e.g., with Tasmota), the Lamp's Primary controller will lose its ability to "speak" to the bulb unless you rewrite the light control logic in the Primary firmware.
* **Updates:** Firmware updates for the bulb are handled by the manufacturer. You can find more details at the [Kauf RGBWW GitHub](https://github.com/KaufHA/kauf-rgbww-bulbs).

---

### 2. Primary Controller
The Primary ESP32 acts as the "brain" for logic and external integrations. When working with the source code, the firmware consists of two primary files:

* **`bedside_lamp.ino`**: The main C++ source code containing the logic, MQTT handling, and hardware control.
* **`html.h`**: A critical header file containing the entire web application (HTML, CSS, and JavaScript) as embedded strings.

**Release Binaries:** 
- `Primary_Ctrl_vx.xx_Full.bin` - For new installs.  Overwrites flash and creates partitions before installation.  Any existing configurations (including WiFi credentials) will be lost.
- `Primary_Ctrl_vx.xx_Update.bin` - For upgrading existing installations.  Configuration will be maintained.  Will not work on 'new' boards that do not have a prior copy of the firmware installed.

*(The .bin files contain the compiled output of both the .ino and .h files.)*

---

### 3. Display Controller
The Display ESP32 handles the touch interface, the clock, alarms, and the audio playback. Its source structure includes:

* **`bl_display.ino`**: The core logic for screen rendering and touch response.
* **`html.h`**: The web interface for display-specific settings (like audio library management).
* **`icons20pt7b.h`**: A specialized header file defining the custom font used for the icons shown on the touch panel.

**Release Binaries:**
- `Display_Ctrl_vx.xx_Full.bin` - For new installs.  Overwrites flash and creates partitions before installation.  Any existing configurations (including WiFi credentials) will be lost.
- `Display_Ctrl_vx.xx_Update.bin` - For upgrading existing installations.  Configuration will be maintained.  Will not work on 'new' boards that do not have a prior copy of the firmware installed.

*(The .bin files contain the compiled output of all three source files.)*

---

> **⚠️ The "Don't Cross the Streams" Warning**<br>
> While the files look similar, the pin mappings and logic are fundamentally different. **Never** attempt to flash the Primary firmware to the Display controller or vice versa. Doing so won't just fail; it will likely lock up the controller so hard it will require a manual USB recovery and a very patient afternoon. Verify your file names twice before clicking that "Update" button!
{: .warning }

---

<div style="display: flex; justify-content: space-between; align-items: center; margin-top: 40px; border-top: 1px solid #333; padding-top: 20px;">
  <a href="{{ '/advanced' | relative_url }}" class="btn btn-outline"><- Previous: Advanced Tech Info</a>
  <a href="{{ '/advancedconfig' | relative_url }}" class="btn btn-purple">Next: Configuration Files -></a>
</div>

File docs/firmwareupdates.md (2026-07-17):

---
layout: default
title: Installing Updates
parent: Firmware Updates and Modifications
nav_order: 1
---

# Installing Firmware Updates
{: .no_toc }

---

<p align="center">
  Firmware Update Header
</p>

From time to time, new versions of the firmware are released to provide bug fixes, new features, or support for updated hardware. This section covers how to obtain the latest files and apply them safely to your system.

## Update Notifications
Since the system is designed for local privacy and operates without a constant internet "phone home" connection, there is no automatic push notification for updates within the web app.

To stay informed, it is recommended to "Watch" the official repository:
1. Log into your GitHub account.
2. Navigate to the [Ultimate Bedside Lamp repository](https://github.com/Resinchem/Ultimate-Bedside-Lamp).
3. Set a **Watch** notification for "Releases."

GitHub Watch Notification

Assure you've enable notifcations in your Github settings and you can receive an email or a push notification in Github whenever a new release is published.

## Obtaining the Latest Firmware
The most recent stable files are always located in the **Releases** section of the GitHub repository.

firmwareupdates_08

### Release Notes
Each release includes notes detailing exactly what changed. Some updates may target only one controller, while others update the entire system. All releases will contain both controller's firmware, but the release notes will indicate which files have been updated and which remain the same. 

> **❗ Pay Attention to Breaking Changes**<br>Always check the release notes for a **BREAKING CHANGES** section. These may require you to perform extra configuration steps or hardware adjustments during the upgrade process.
{: .important }

_Example of a Breaking Changes section in release notes:_<br>
firmwareupdates_09

### Which file do I need?
If you are running the standard, unmodified firmware, you only need the `.bin` files under the release's assets:
* **Primary Controller:** `Primary_Ctrl_vX.XX_Update.bin`
* **Display Controller:** `Display_Ctrl_vX.XX_Update.bin`

*(X.XX represents the version number)*

Releases also contain **_Full** versions as well, but these are meant for **initial or new installs** only.  If you install a **_Full** version over an existing installation, all your settings (including WiFi credentials) will be overwritten and you will have to onboard and configure your system again.

_You do not need the Source code files unless you are looking to modify the firmware_.

## Installing the Update
> **⚠️ WARNING: Files are NOT Interchangeable**<br>The Primary and Display controllers use different pin mappings and logic. **Double-check your files!** Sending the Display firmware to the Primary controller (or vice versa) is a quick way to turn your smart lamp into a very confused (and dark) paperweight. You will likely need to reflash via a USB cable to recover.
{: .warning }

1. Navigate to the **Controller Commands** section of the controller you wish to upgrade.
2. Click the **Firmware Upgrade** button.

Firmware Upgrade Buttons

3. On the upgrade page, verify the **Background Color** (Gray for Primary, Yellow for Display) to ensure you are on the correct display's page.  You can also check the labels and current version number as extra confirmation.

&nbsp;&nbsp;&nbsp;&nbsp;&nbsp;&nbsp;&nbsp;&nbsp;&nbsp;&nbsp;&nbsp;Upgrade Interface

4. Click **Choose File** and select the `.bin` file you downloaded.

5. Click **UPDATE**.<br>
    > **⚠️ Caution**<br>Once the update starts, resist the urge to tinker. It only takes a minute, and interrupting a flash is the digital equivalent of waking a sleepwalker—it rarely ends well.
{: .important }

<br>

A progress bar will appear. Once the upload reaches 100%, the controller will automatically reboot.

## Verifying the Update
Once the system reboots, navigate to the top of the controller's main page. The version string in the header should now reflect the updated version number.

Version Verification

If the old version number is still displayed, the update failed and the system successfully "rolled back" to the previous firmware. You can attempt the flash again or consult the [Troubleshooting]({{ '/troubleshooting' | relative_url }}) guide.

## Using Third-Party Utilities
While the internal web update is the recommended path, utilities like [ESPConnect](https://thelastoutpostworkshop.github.io/ESPConnect/) can be used as a fallback.

> **⚠️ Critical: Partition Layouts**<br>Due to the complexity of the firmware, this project uses non-standard partition sizes. 
> * **DO NOT** select "Erase Flash" before flashing; this will wipe your configuration files and Wi-Fi credentials.
> * Your utility **must** support custom partition offsets. Failure to respect the partition layout will result in a boot failure.  See [Advanced](/advanced.md) topics for information on required partitions.
{: .warning }

## Updating Modified Firmware
If you have customized the C++, HTML, or CSS, applying an official `.bin` update **will overwrite all your changes.** You must instead pull the updated source code from GitHub and re-apply your modifications manually before compiling.

<div style="display: flex; justify-content: space-between; align-items: center; margin-top: 40px; border-top: 1px solid #333; padding-top: 20px;">
  <a href="{{ '/firmwaremain' | relative_url }}" class="btn btn-outline"><- Previous: Firmware Updates</a>
  <a href="{{ '/modifications' | relative_url }}" class="btn btn-purple">Next: Modifying the Firmware -></a>
</div>

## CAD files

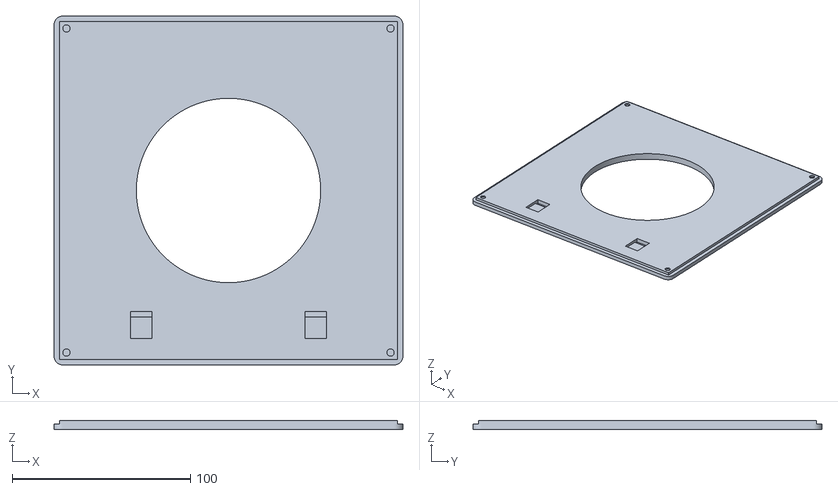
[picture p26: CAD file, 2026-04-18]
stl/Main Enclosure Lid.stl
196.0 x 196.0 x 5.00

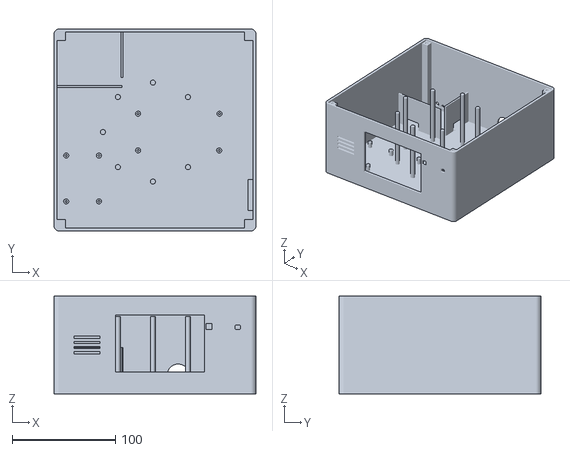
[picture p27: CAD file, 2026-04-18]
stl/Main Enclosure Base.stl
196.0 x 196.0 x 95.0

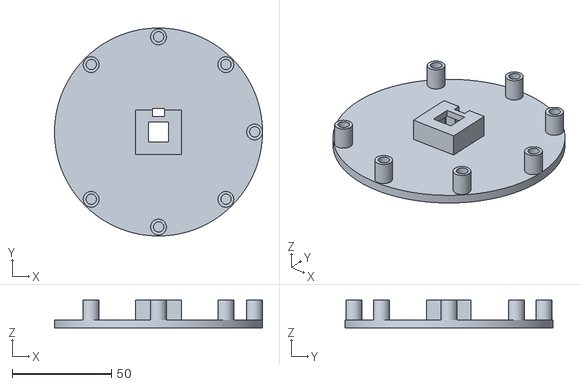
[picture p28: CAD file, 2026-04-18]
stl/Bottle Platform.stl
105.0 x 105.0 x 14.0

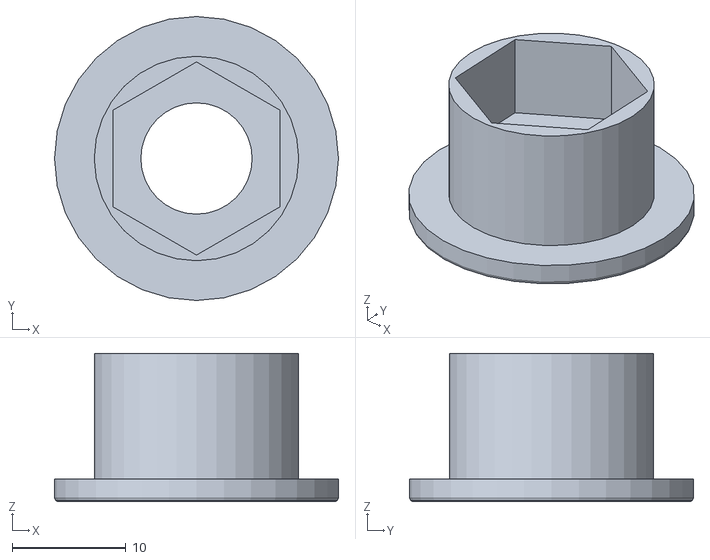
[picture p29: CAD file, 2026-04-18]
stl/Bottle Adapter.stl
25.0 x 25.0 x 13.1

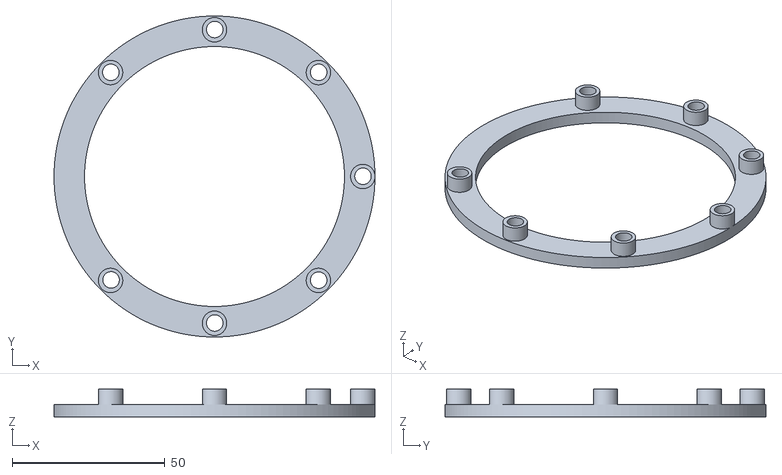
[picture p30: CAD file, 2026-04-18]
stl/Midplatform Support.stl
105.0 x 105.0 x 9.00

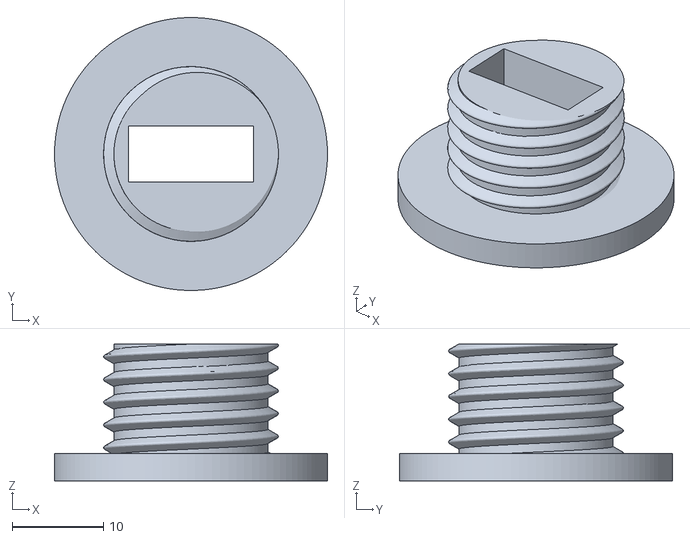
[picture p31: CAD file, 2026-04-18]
stl/USBPort Mount.stl
30.0 x 30.0 x 15.0

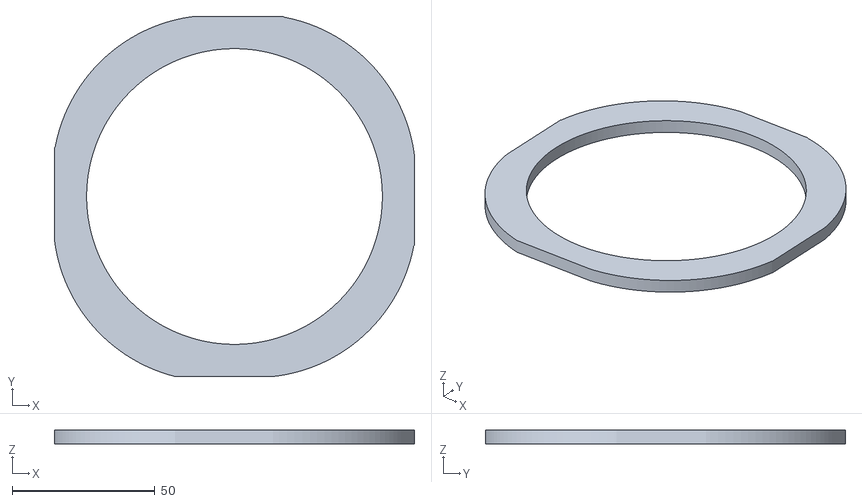
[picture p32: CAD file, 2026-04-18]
stl/Bottle Sizer.stl
126.0 x 126.0 x 5.00

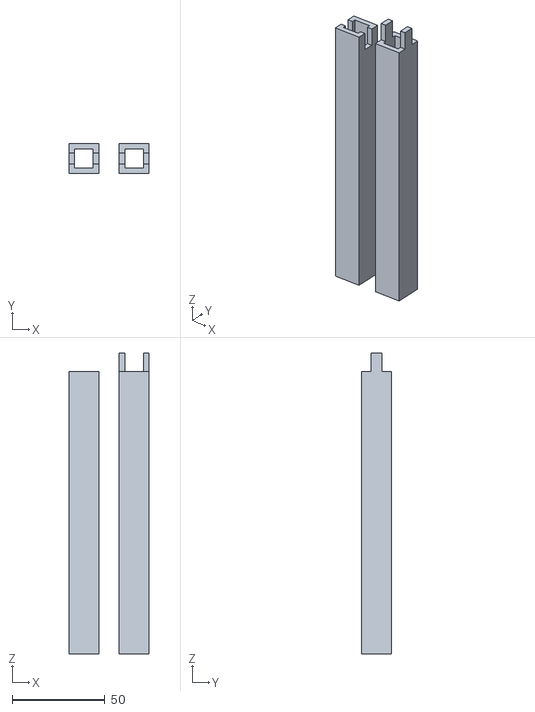
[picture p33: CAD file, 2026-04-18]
stl/Bottle Center Shaft.stl
43.0 x 16.0 x 162.0

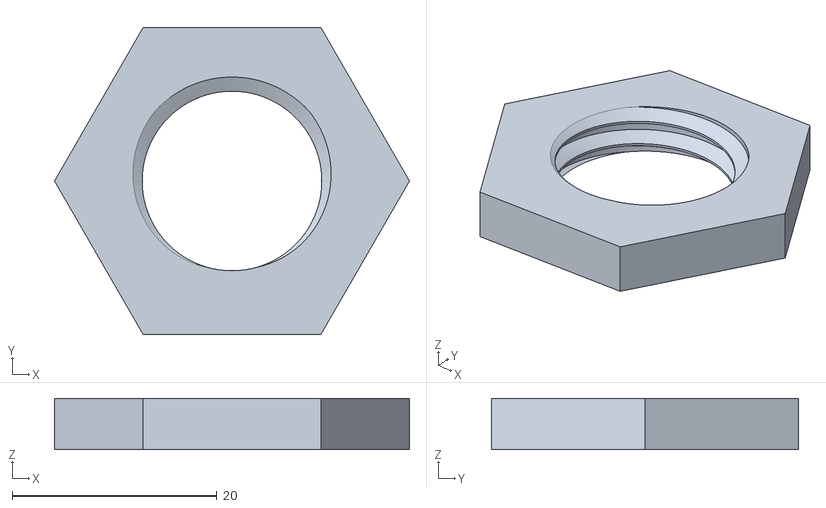
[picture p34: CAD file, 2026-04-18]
stl/USBPort Nut.stl
34.6 x 30.0 x 5.00

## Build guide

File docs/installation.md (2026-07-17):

---
layout: default
title: Initial Firmware Installation
parent: Getting Started
nav_order: 1
has_toc: false
---

# Initial Firmware Installation
{: .no_toc }

---

<p align="center">
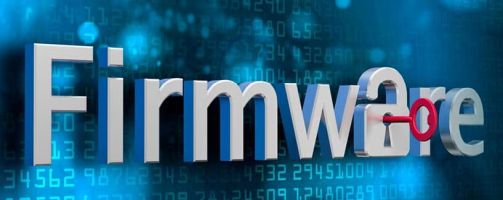
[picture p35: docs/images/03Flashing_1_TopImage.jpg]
Initial Firmware Installation
  
</p>

The first preparation step you need to complete is the installation of the firmware onto the controllers. This process is called **flashing**. Historically, this was one of the steps that caused the most frustration due to the need for specific desktop utilities and complex settings.

To make this process as simple as possible, we now use a modern, browser-based tool called **ESPConnect**.

03_02_ESPConnLogo

[ESPConnect](https://thelastoutpostworkshop.github.io/ESPConnect/) is a free, open-source web tool for interacting with ESP32-based microcontrollers. It allows you to flash firmware directly from your browser using the same technology found in tools for WLED, Tasmota, and ESPHome.  This is what will be shown in this guide for the firmware installation step, but other alternatives will also be covered.

---

## Prerequisites

To complete the installation, you will need:
* **Hardware:** A computer with an available USB port and a **microUSB Data Cable**. (Note: "Power-only" cables will not work).
* **Firmware:** A copy of the firmware `_Full.bin` files (available in the [Releases](https://github.com/Resinchem/Ultimate-Bedside-Lamp/releases) area of the repository).
* **Software:** A Chromium-based browser (Chrome, Edge, Brave, or Arc) version 89 or newer.
 
**🖥️ Browser Alternatives**<br>If you do not wish to use a Chromium-based browser, you must use traditional desktop flashing utilities. For guidance on that method, you can refer to my [Beginner's Guide to Flashing Custom Firmware](https://youtu.be/74NGHj-cOls) video (skip to the **8:08** mark).
{: .note }

---

## Kauf RGBW Wi-Fi Bulb

**No installation is necessary for the bulb!** The device comes pre-installed with the required firmware. 

**Do not attempt to flash any other firmware to the bulb.** Replacing the official Kauf ESPHome firmware will cause the device to fail within this project. If you wish to make minor changes (such as the device name), use the official ESPHome code provided by the manufacturer.
{: .label .label-yellow }

---

## Primary and Display Controllers

The process for both controllers is identical. The only difference is the firmware `.bin` file used:

* **Primary Controller:** Use `Primary_Ctrl_vx.xx_Full.bin`
* **Display Controller:** Use `Display_Ctrl_vx.xx_Full.bin`

*(Note: `vx.xx` represents the version number. Always use the most recent versions found in the assets section of the [latest release](https://github.com/Resinchem/Ultimate-Bedside-Lamp/releases/latest).*

Releases may also contain **\_Update.bin** files for each controller.  These are meant for _upgrading an existing system_ and not for new installs.  Attempting to install an update file to a new controller will likely fail and may put the ESP32 into a boot loop.

### Step 1: Connect to ESPConnect
Open a Chromium-based browser and navigate to the [ESPConnect Tool](https://thelastoutpostworkshop.github.io/ESPConnect/).

<p>
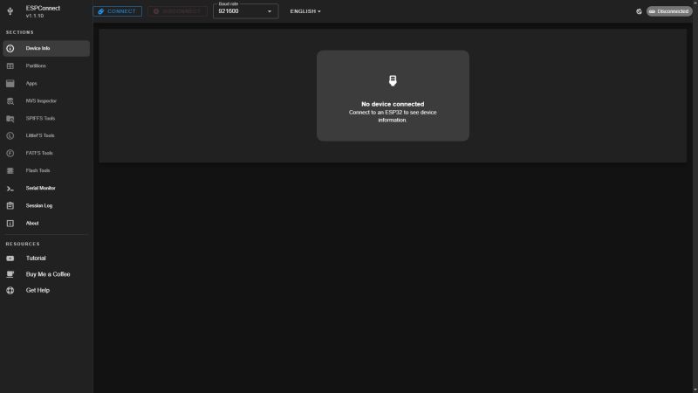
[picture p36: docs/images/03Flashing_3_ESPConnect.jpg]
ESPConnect Tool Interface
  
</p>

If you haven't done so yet, connect the controller (the ESP32 for primary, or the Cheap Yellow Display for display) and click the **Connect** button in the upper-left corner.

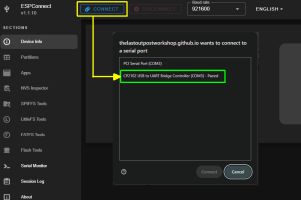
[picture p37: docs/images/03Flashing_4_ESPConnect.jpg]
03_04_ESPConnect


Select the appropriate **COM Port**. 

**🖥️ USB Drivers: The Invisible Gatekeepers**<br>If your computer treats your ESP32 like an unrecognized alien artifact, you might be using a charge-only USB cable. Don’t feel bad; even the most seasoned developers have spent an hour troubleshooting a board only to realize they were using a "charge-only" USB cable they found in the back of a drawer. If you don't see a new COM port appear, try a different cable before you start questioning your life choices.
{: .important }

**🔍 Troubleshooting COM Ports**<br>If you aren't sure which port to pick, disconnect the ESP32 and check the list; the port that disappears is your device. If no ports appear (and you are using a known, good USB data cable), you may need to install the **CP2102** or **CH340** USB-to-Serial drivers for your specific hardware.
{: .note }

### Step 2: Configure Flash Settings
Once connected, complete the following steps.

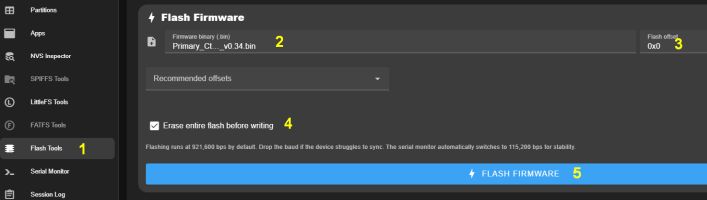
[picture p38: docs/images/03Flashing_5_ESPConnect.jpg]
03_05_ESPConnect


1. **Select Flash Tools**: Select the Flash Tools option from the sidebar menu.
2. **Select Firmware:** Click the Firmware Binary box and select the proper `.bin` file for the controller you are flashing.
3. **Flash Offset:** Leave this at the default **0x0**.
4. **Erase Flash\*:** Check the **Erase entire flash** checkbox to ensure a clean installation.
5. **Install:** Click the large blue "Flash Firmware" button to start the upload process.

**⚠️ *Only Erase Flash for New Installs!**<br>If you are using this method to _upgraded_ the firmware on an existing controller, **clear the 'Erase enttire flash' checkbox** or your existing configuration, WiFi connection info, etc. will be lost and you will have to onboard and configure the controller again.  See [Installing Updates](/firmwareupdates.md) for details.
{: .critical }

### Step 3: Flash and Verify
ESPConnect will show a progress bar during the flashing process:

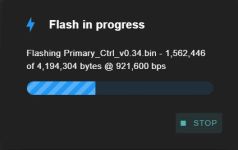
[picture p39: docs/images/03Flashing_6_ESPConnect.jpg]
!03_06_ESPConnect


Once the flashing is complete, power cycle the ESP32 by unplugging and reconnecting it to the USB port. Wait a few moments, then use your phone or computer to scan for available Wi-Fi networks:

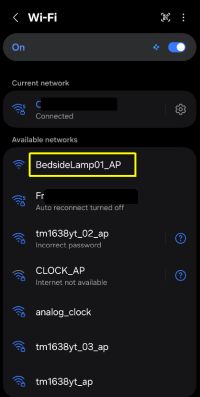
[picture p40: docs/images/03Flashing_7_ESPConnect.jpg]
03_07_ESPConnect


**Success Criteria:** If you see a Wi-Fi hotspot named `BedsideLamp01_AP` (or `BL_Display01_AP` for the display), the flash was successful.

**⏹️Hotspot Name**<br>Note that the hotspot shown may use the assigned device name followed by '_AP' (e.g. _MyDeviceName_AP_) instead of the defaults.  This is likely if onboarding a previously used controller, but may happen with new installs as well if initial onboarding fails.  The correct AP should be obvious as long as you use a descriptive device name.
{: .note }

---

### Next Steps
Repeat the above steps for the second controller. Once both are flashed and broadcasting their respective hotspots, you are ready to join them to your Wi-Fi network. This is covered in the next section, [Onboarding and First Time Setup]({{ '/onboarding' | relative_url }}).

<div style="display: flex; justify-content: space-between; align-items: center; margin-top: 40px; border-top: 1px solid #333; padding-top: 20px;">
  <a href="{{ '/startingmain' | relative_url }}" class="btn btn-outline"><- Previous: Getting Started</a>
  <a href="{{ '/onboarding' | relative_url }}" class="btn btn-purple">Next: Onboarding -></a>
</div>

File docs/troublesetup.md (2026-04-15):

---
layout: default
title: Initial Setup & Connectivity
parent: Troubleshooting
nav_order: 1
---

# Initial Setup & Connectivity
{: .no_toc }

---

<p align="center">
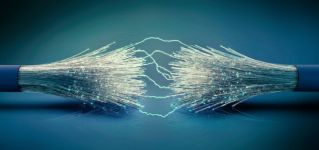
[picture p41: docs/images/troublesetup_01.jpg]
[Troubleshooting image]
  
</p>

This section covers the initial flashing of the binary firmware and the onboarding steps. If you are attempting an upgrade of existing firmware or are trying to flash source code from an IDE, please refer to the [Firmware Updates]({{ '/firmwaremain' | relative_url }}) or [Advanced Technical Information]({{ '/advanced' | relative_url }}) sections instead.

## Installation Issues
Getting the firmware onto the ESP32 is usually the hardest part. If the computer and the controller aren't talking, check these common culprits.

### No COM Port Found
When you connect your standalone ESP32 (Primary) or the Cheap Yellow Display (Display) to your PC, you must select a COM port. If no new port appears, you are likely missing the USB-to-Serial drivers.

> **💡 Note**<br>These drivers are provided by third parties. Use caution when downloading and installing files. If the standard drivers fail, check your PC manufacturer's site (especially for Lenovo laptops).
{: .note }

* **[CP2012 Drivers](https://www.silabs.com/software-and-tools/usb-to-uart-bridge-vcp-drivers?tab=overview)** – Windows and Mac.
* **CH342, CH343, CH9102 Drivers:** **[Windows](https://www.wch.cn/downloads/CH343SER_ZIP.html)** \| **[Mac](https://www.wch.cn/downloads/CH34XSER_MAC_ZIP.html)**
* **CH340, CH341 Drivers:** **[Windows](https://www.wch.cn/downloads/CH341SER_ZIP.html)** \| **[Mac](https://www.wch.cn/downloads/CH341SER_MAC_ZIP.html)**

*If the driver pages appear in Chinese, right-click and select "Translate to English" in your browser, or look for the "down arrow" (↓) download button. I did not develop nor am I reponsible for these drivers.*

### ESP32 Will Not Connect
If the drivers are installed but the board won't connect, you may need to perform the "Boot Button Dance" to force the board into flashing mode:

1. Hold down the **BOOT** button on the ESP32.
2. Apply power (plug in USB) or press the **EN/RESET** button while still holding BOOT.
3. Release both buttons simultaneously.

### Flash Succeeds, but no Hotspot Appears
If the flash finishes but you don't see an onboarding access point, the flash was likely incomplete or corrupt. Erase the flash and try again. If the problem persists, try a different utility:

1. **[ESPConnect](https://thelastoutpostworkshop.github.io/ESPConnect/) (Recommended)** – Requires a Chromium-based browser and internet connection.
2. **[ESPHome Web Flasher](https://github.com/esphome/esphome-flasher/releases/latest)** – A reliable desktop alternative.
3. **[NodeMCU PyFlasher](https://github.com/nodemcu/nodemcu-flasher)** – Use as a last resort (Windows only).

If all else fails, you may need to try compiling and flashing the source code from the Arduino IDE. It is possible that there is a compatiblity issue with your particular ESP32. See [Modifying the Firmware](/modifications.md) for more information on using the Arduino IDE to flash the firmware.

## Onboarding Issues
Once the flash is successful, the controller broadcasts a Wi-Fi hotspot. You should see a network named: `deviceName_AP` (where `deviceName` is what you entered during onboarding).

* **Check the Network:** Ensure your phone or laptop is searching on the same Wi-Fi frequency (2.4GHz).
* **Proximity:** The ESP32 doesn't have the broadcasting power of a high-end router. Stay in the vicinity of the controller during this process.
* **Wait for it:** It can take 2–3 minutes for the hotspot to initialize. If it never appears after a power cycle, refer back to the flashing troubleshooting above.

## Obtaining the Controller IP Address
Usually, your router’s DHCP list will show the device by the name you gave it. If you're stuck:

* **Display Controller:** The IP address is listed on the screen during the boot process.
* **Primary Controller:** Since there is no screen, you will need a network scanning tool (like Fing) or your router's admin page to find the IP address via the device's MAC address.

<div style="display: flex; justify-content: space-between; align-items: center; margin-top: 40px; border-top: 1px solid #333; padding-top: 20px;">
  <a href="{{ '/troubleshooting' | relative_url }}" class="btn btn-outline"><- Previous: Troubleshooting Overview</a>
  <a href="{{ '/troubleoperation' | relative_url }}" class="btn btn-purple">Next: Operation & Configuration  Issues-></a>
</div>

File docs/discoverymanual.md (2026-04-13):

---
layout: default
title: Manually Creating MQTT Entities
parent: Home Assistant Discovery
nav_order: 3
---

# Manually Creating MQTT Entities
{: .no_toc }

---

<p align="center">
  [PLACEHOLDER: Manual YAML Configuration]
</p>

While the "One-Click" Discovery is recommended for most users, some Home Assistant enthusiasts prefer the precise control afforded by manual YAML configuration. This method allows you to define unique IDs, specific icons, and custom availability logic directly in your configuration files.

> **❗ Advanced Users Only**<br>Manually creating MQTT entities requires a solid understanding of Home Assistant’s YAML structure and MQTT integration. If you are not comfortable editing `configuration.yaml`, it is highly recommended to use the [Automatic Discovery]({{ '/discoverymanage' | relative_url }}) instead.
{: .important }

---

### YAML Example: Auto-Dimming Switch
If you choose the manual path, you must ensure your topics match the **Publish** and **Subscribe** topics defined in your [MQTT Settings]({{ '/mqtt' | relative_url }}).

Below is an example of how the **Auto-Dimming** entity might be defined in your Home Assistant configuration. 

*Note: This example assumes your chosen topic is `bedlamp`.*

```yaml
mqtt:
  - switch:
      unique_id: bedlamp_autodim
      name: "Auto Dimming"
      state_topic: "stat/bedlamp/autodim"
      command_topic: "cmnd/bedlamp/autodim"
      availability:
        - topic: "stat/bedlamp/display/status"
      payload_on: "ON"
      payload_off: "OFF"
      state_on: "ON"
      state_off: "OFF"
      optimistic: false
      qos: 0
      retain: true    
```

### Further Reference
Because the Home Assistant environment evolves frequently, the firmware is designed to follow standard MQTT conventions. For a comprehensive guide on creating lights, binary sensors, and buttons via YAML, please refer to the official documentation:

* **[Home Assistant MQTT Integration Documentation](https://www.home-assistant.io/integrations/mqtt/)**

---

<div style="display: flex; justify-content: space-between; align-items: center; margin-top: 40px; border-top: 1px solid #333; padding-top: 20px;">
  <a href="{{ '/discoveryentities' | relative_url }}" class="btn btn-outline"><- Previous: Editing or Hiding Entities</a>
  <a href="{{ '/firmwaremain' | relative_url }}" class="btn btn-purple">Next: Firmware Updates -></a>
</div>

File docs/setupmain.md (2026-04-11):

---
layout: default
title: Setting Up the System
nav_order: 4
has_children: true
has_toc: false
---

# Setting Up the System
{: .no_toc }

---

<p align="center">
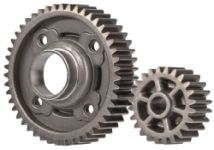
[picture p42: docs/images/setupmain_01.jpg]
System Setup Header
  
</p>

Once the system has been onboarded and the controllers are speaking to one another, you can begin to configure the system for your particular needs, select a time and weather source, and more.

This section covers the core configuration of your hardware and environmental data:

* **[Web App Overview]({{ '/webapp' | relative_url }})** - Accessing the app and understanding the interface.
* **[Main Display]({{ '/display' | relative_url }})** - Configuring the display and enable touch capabilities.
* **[Auto-Dimming]({{ '/autodim' | relative_url }})** - Managing brightness for bedroom use.
* **[Lights]({{ '/lights' | relative_url }})** - Controlling the RGBW Bulb and LED Strip.
* **[Clock and Time]({{ '/time' | relative_url }})** - Setting time sources, fonts, and colors.
* **[Temperature and Weather]({{ '/weather' | relative_url }})** - Configuring outdoor environmental data.
* **[Touch Sensors]({{ '/touchsensors' | relative_url }})** - Enabling and configuring the independent touch sensors.

> **💡 Configuration Logic**<br>It is important to understand that the system manages two distinct "sets" of settings:
> * **Default Settings:** Saved values loaded when the system first starts up or reboots.
> * **Active Settings:** Values currently in use (which may be temporary until the next reboot).
>
> This distinction is covered in more detail in the [Web App Overview]({{ '/webapp' | relative_url }}).
{: .note }

---

<div style="display: flex; justify-content: space-between; align-items: center; margin-top: 40px; border-top: 1px solid #333; padding-top: 20px;">
  <a href="{{ '/booting' | relative_url }}" class="btn btn-outline"><- Previous: The Boot Process</a>
  <a href="{{ '/webapp' | relative_url }}" class="btn btn-purple">Next: Web App Overview -></a>
</div>

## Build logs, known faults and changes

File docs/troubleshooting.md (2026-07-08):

---
layout: default
title: Troubleshooting
nav_order: 11
has_children: true
has_toc: false
---

# Troubleshooting
{: .no_toc }

---

<p align="center">
  Troubleshooting Overview
</p>

If you find there is a "ghost in the machine" or your lamp isn't behaving as expected, don't panic. Electronics can be finicky, but most issues can be resolved with a bit of systematic checking. 

Before diving into the specific fixes below, first verify that you have reviewed the applicable sections throughout this document and the [Build Guide](https://resinchemtech.blogspot.com/2026/05/ultimate-bedside-lamp.html) to ensure a step wasn't missed during the assembly or configuration process.

---

### 🛑 The Golden Rule of Hardware
As emphasized throughout this project, **the firmware is designed to work with very specific hardware components.** 

> **❗ Support Disclaimer**<br>
> I am unable to provide technical support for builds that use substituted hardware components. If you decide to go "off-book" with different screens, sensors, or controllers, you are officially the lead engineer for that version! Please don't ask for custom firmware modifications for unsupported hardware.
{: .important }

**A Note on the Kauf Bulb:** The RGBW light bulb uses its own factory-installed firmware. If your issues are specific to the bulb's internal software (and not how the lamp talks to it), please consult the [Kauf Bulb GitHub](https://github.com/KaufHA/kauf-rgbww-bulbs) for assistance.

---

### Triage: Where is the problem?

To help you find a solution without scrolling through pages of unrelated text, the troubleshooting guide is broken down into the following categories:

* **[Initial Setup & Connectivity]({{ '/troublesetup' | relative_url }})** – Issues with COM ports, USB drivers, flashing errors, and the initial onboarding hotspot.
* **[Daily Operation & Configuration]({{ '/troubleoperation' | relative_url }})** – Problems with "Save & Reboot" persistence, firmware update failures, and reviewing Config Dumps.
* **[Home Assistant & MQTT]({{ '/troublediscovery' | relative_url }})** – Discovery issues, "stuck" MQTT topics, and integration prerequisites.
* **[FAQ & Getting Help]({{ '/troublefaq' | relative_url }})** – Frequently Asked Questions and the proper etiquette for opening a GitHub Issue or starting a Discussion.

---

<div style="display: flex; justify-content: space-between; align-items: center; margin-top: 40px; border-top: 1px solid #333; padding-top: 20px;">
  <a href="{{ '/advancedpartitions' | relative_url }}" class="btn btn-outline"><- Previous: Partitions and Flashing</a>
  <a href="{{ '/troublesetup' | relative_url }}" class="btn btn-purple">Next: Initial Setup Troubleshooting -></a>
</div>

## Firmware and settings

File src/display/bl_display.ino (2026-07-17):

/* =================================================================
 * Bedside Lamp: CYD Touch Display
 * July, 2026
 * Version 0.53
 * Copyright ResinChemTech - released under the GPL-3.0 license
 * ================================================================= */

#include <WiFi.h>                 //Core WiFi services
#include <WiFiClient.h>           //Arduino ESP Core - creates a client that can connect to an IP address
#include <ESPping.h>              //v1.0.5 - ping remote IP to test connectivity (e.g bulb, display, etc.)
#include <ESPmDNS.h>              //mDNS service for Arduino OTA updates
#include <WebServer.h>            //Local web server (for settings pages)
#include <LittleFS.h>             //Read and write to flash storage
#include <Wire.h>                 //I2C
#include <SPI.h>                  //SPI
#include <SoftwareSerial.h>       //For DFPlayer Serial 
#include "DFRobotDFPlayerMini.h"  //MP3 Player: https://github.com/DFRobot/DFRobotDFPlayerMini (v.1.0.6)
#include "time.h"                 //Time functions
#include <HTTPClient.h>           //For sending HTTP requests
#include <WiFiClientSecure.h>     //for sending HTTPS requests
#include "esp_sntp.h"             //SNTP functions
#include <ESP32Time.h>            //For setting and getting RTC time from ESP32: https://github.com/fbiego/ESP32Time (v2.0.6)
#include <ArduinoJson.h>          //Reading and writing JSON files (e.g. config file)
#include <WiFiUdp.h>              //WiFi UDP functions
#include <ArduinoOTA.h>           //OTA Updates via Arduino IDE
#include <Update.h>               //OTA Updates via web page
#include <PubSubClient.h>         //https://github.com/knolleary/pubsubclient  Provides MQTT functions (v2.8)
#include "initGT911.h"            //Touch library https://github.com/milad-nikpendar/initGT911 (v1.0.1 - manually installed via .zip to fix rotation issue)
#include <TFT_eSPI.h>             //Main Display Library - See TFT_eSPI User_Setup_Select.h for using a different "CYD" version: https://github.com/Bodmer/TFT_eSPI
#include <TFT_eWidget.h>          //Additional features and widgets: https://github.com/Bodmer/TFT_eWidget (v0.0.5)
#include <ESP_Knob.h>             //Rotary Encoder (EC11) Library: https://github.com/esp-arduino-libs/ESP32_Knob (v0.0.1)
#include "html.h"                 //html code for the web settings pages
#include "icons20pt7b.h"          //Custom icon font for top of display
 
#define VERSION "v0.53"
#define APPNAME "LAMP DISPLAY"
#define WIFIMODE 2                // 0 = Only Soft Access Point, 1 = Only connect to local WiFi network with UN/PW, 2 = Both (both needed for onboarding)
#define SERIAL_DEBUG 0            // 0 = Disable (must be disabled if using RX/TX pins), 1 = enable

#define FORMAT_LITTLEFS_IF_FAILED true  // DO NOT CHANGE
#define GFXFF 1
// ==========================================================================
//  *** REVIEW AND UPDATE THESE VARIABLES TO MATCH YOUR ENVIRONMENT/BUILD ***
// ==========================================================================
//Pin Definitions - Update if your build is different
// Display & Touch pins and frequency
#define DISP_I2C_SDA 33
#define DISP_I2C_SCL 32
#define DISP_I2C_FREQ 400000
#define DISP_RST_PIN  25       // Display reset pin
#define DISP_INT_PIN -1        // Display interrupt - not used in polling mode (-1)
#define DISP_BL_PIN 27         // LED Backlight
#define DISP_LDR 35            // Displays built-in LDR
//Onboard LED
#define RED_LED_PIN 4          
#define GREEN_LED_PIN 16
#define BLUE_LED_PIN 17

//DFPlayer Serial GPIOs
#define DF_RX 22  //blue (old 19)
#define DF_TX 21  //yellow (old 23)

//Onboard LED freq and resoultion
#define LED_FREQ 5000
#define LED_RES 8                        //8 bit resolution (e.g. 0-255)
//Display Dimensions & Touch Address
//Only change if your display is different (you may also need to edit the TFT_eSPI setup and recompile)
#define DISP_H 480                       //Init horizontal resolution (in pixels) - can be changed via app after onboarding
#define DISP_V 320                       //Init vertical resoultion (in pixels) - can be changed via app after onboarding 
// GT911 I2C touch address
#define TOUCH_ADDR GT911_I2C_ADDR_BA     //Decimal 93 (Alternate addr: GT911_I2C_ADDR_28 or Decimal 20)
//Alarms & Sounds
#define MAX_ALARMS 5
#define MAX_SOUNDS 20
#define dfSerial Serial1
//MQTT Handling - needed to handle in main loop and to avoid thread conflicts
#define MSK_BRIGHTNESS   0x0001
#define MSK_AUTODIM      0x0002
#define MSK_COLOR        0x0004
#define MSK_GENTLE       0x0008
#define MSK_TRACK        0x0010
#define MSK_VOLUME       0x0020
#define MSK_SNOOZE       0x0040
#define MSK_ALARMS       0x0080
#define MSK_TEMP         0x0100
#define MSK_TIMESYNC     0x0200
// -------------------------------------------------------
//  The following values are default/starting values.
//  Most can be changed via the app after onboarding and
//  **do not** need to be modified directly here.
// -------------------------------------------------------
#define DISP_ROTATE 3                          //Init display rotation (in degrees 0: 0°, 1: 90°, 2: 180, 3: 270) - can be changed via app after onboarding
#define TIMEZONE "EST+5EDT,M3.2.0/2,M11.1.0/2" // Set your custom time zone from this list: https://github.com/nayarsystems/posix_tz_db/blob/master/zones.csv

/* ================ Default Starting Values ====================================
 * All of these following values can be modified and saved via
 * the web interface and the values below normally do not need to be modified.
 * Using the web settings is the preferred way to change these default values.  
 * Values listed here are just starting values before the config file exists or
 * if it can't be read.
 ===============================================================================*/
//----------------------------------
// Local Variables (wifi/onboarding)
//----------------------------------
String deviceName = "BL_Display01";  //Default Device Name - 16 chars max, no spaces.
String wifiHostName = deviceName;
String wifiSSID = "";
String wifiPW = "";
byte macAddr[6];                     //Array of device mac address as hex bytes (reversed)
String strMacAddr;                   //Formatted string of device mac address
String baseIPAddress;                //Device assigned IP Address
bool onboarding = false;             //Will be set to true if no config file or wifi cannot be joined

//----------------------------------
//Local Variables (Display/Touch)
//----------------------------------
uint16_t dispHeight = DISP_H;            //Local var for display horizontal resolution
uint16_t dispWidth = DISP_V;             //Local var for display vertical resolution
byte defaultDispRotate = DISP_ROTATE;    //Local var for setting/changing display rotation (0: 0°, 1: 90°, 2: 180° or 3: 270°)
byte activeDispRotate = DISP_ROTATE;
byte defaultBrightness = 128;            //Starting local brightness (will be overwritten by config file)
byte activeBrightness = 128;
byte holdBrightness = 128;
byte holdEditBrightness = 0;
bool overrideBrightness = false;         //Used on touch to temporarily increase brightness if less than default
uint32_t overrideTimer = 0;              //Timer for brightness override (will be 5 seconds by default)
bool useLED = false;                     //Use onboard LED
byte activePage = 0;                     //Tracks currently displayed page on display (0 = default clock page)
byte lastPage = 99;                      //For clearing/refreshing page when page changes
byte alarmEditNum = 0;                   //Alarm slot num being edited via touch screen (0 based array)
bool alarmEdited = false;                //Alarm has been edited via touch panel (but not yet saved)

//Touch
String touchAddr = "GT911_I2C_ADDR_BA";  //Touch address (either GT911_I2C_ADDR_BA or GT911_I2C_ADDR_28)
bool touchEnabled = false;               //Enable touch screen functions
bool touchEnabledTest = false;           //Temporarily enable touch for testing
unsigned long lastTouchScan = 0;         //For the 100ms polling interval
unsigned long touchCooldownTime = 0;     //To ignore touches briefly after state changes
unsigned long lastTouchTime = 0;         //Tracks last touch for auto-closing settings (no touch for >10 seconds)
//Global timing variables for touch scrolling
uint32_t lastScrollMillis = 0;
uint16_t scrollDelay = 400;

//Auto-Dimming
bool autoDim = false;                    //Enable or disable auto-dimming
bool autoDimActive = false;              //For tracking temp auto-dim changes
byte autoDimDebounce = 1;                //Auto dim debounce cycles (1 cycle ~ 1 sec). 0 min 10 max
byte ambLightLevel_1 = 0;
byte ambLightLevel_2 = 0;
byte ambLightLevel_3 = 0;
byte ambLightLevel_4 = 0;
byte dimBrightness_1 = 25;
byte dimBrightness_2 = 75;
byte dimBrightness_3 = 125;
byte dimBrightness_4 = 175;
byte dimBrightness_5 = 225;
uint32_t dimLastCheckMillis = 0;
byte activeThresholdMin = 0;
byte activeThresholdMax = 0;
byte crossedThresholdCount = 0;
//Testing vars (Holding values)
bool displayTestFlag = false;
byte displayTestRotate = 0;
byte displayTestBrightness = 0;
bool displayTestTouch = false;
bool holdAutoDim = false;
String whichData = "all";

//Display Settings Page
bool bulbState = false;
bool ledState = false;
bool lightStateChange = false;
bool dimStateChange = false;
bool brightChange = false;
//----------------------------------
//Local Variables (MQTT/Discovery)
//----------------------------------
//  MQTT will only be used if a server address other than '0.0.0.0' is entered via portal
byte mqttAddr_1 = 0;
byte mqttAddr_2 = 0;
byte mqttAddr_3 = 0;
byte mqttAddr_4 = 0;
int mqttPort = 0;
String mqttIPAddress = "";
String mqttClient = "bldisplay";
String mqttUser = "myusername";
String mqttPW = "mypassword";
uint16_t mqttTelePeriod = 60;          //seconds - how often MQTT is updated (outside of state changes)
uint32_t lastMqttRetryAttempt = 0;     //Non-blocking handler for MQTT reconnection
const int MQTT_RETRY_DELAY = 5000;     //Delay (ms) between reconnect attempts
String mqttTopicSub ="bldisplay";      //Can be changed via web app (preferred method)
String mqttTopicPub = "bldisplay";     //Can be changed via web app 
String mqttClockColor = "#ffffff";     //Color intent to handle 24-bit to 16-bit conversion for tft display

bool mqttEnabled = false;              //Will be enabled/disabled depending on whether a valid IP address is defined in Settings (0.0.0.0 disables MQTT)
bool mqttConnected = false;            //Will be enabled if defined and successful connnection made.  This var should be checked upon any MQTT action.
bool forceMQTTUpdate = false;          //Force MQTT update on state change

char globalMqttBuffer[1024];           //Buffer for publishing alarm data to MQTT
bool initialSyncRequired = false;      //Flag for initial publish of MQTT data after boot
int syncStep = 0;
bool rebootRequired = false;
unsigned long lastSyncStepTime = 0;
volatile uint32_t mqttUpdateMask = 0;  //Volatile so it can be updated by out-of-thread background tasks
const int INIT_SYNC_INTERVAL = 200;    //200ms between publishing
//----------------------------------
//Local Variables (Weather/Temp) 
//----------------------------------
byte defaultTempUnits = 13;            // Show temp in Celcius (12) or Fahrenheit (13)
byte activeTempUnits = 13;
byte weatherSource = 0;                // 0 None, 1 OpenWeatherMap (OWM), 2 MQTT, 3 API
String owmKey = "";                    // Open Weather Map API Key (https://openweathermap.org/api) 
String owmLat = "39.8083";             // Lat/Long defaults point to Lebanon, KS (geographic center of US)
String owmLong = "-98.555";
bool owmConnected = false;             // Boolean indicating if initial connection to OWM is valid (only used if weatherSource is set to OWM)
uint16_t tempUpdatePeriod = 15;        // How often in minutes to request temperature from OWM (minimum 15 min. to limit API calls)
uint32_t lastTempUpdate = 0;
int externalTemperature = 0;

//----------------------------------
// Local Variables (OTA Updates)
//----------------------------------
//OTA Variables
String otaHostName = deviceName + "_OTA";  // Will be updated by device name from onboarding + _OTA
bool ota_flag = true;                      // Must leave this as true for board to broadcast port to IDE upon boot
uint16_t ota_boot_time_window = 2500;      // minimum time on boot for IP address to show in IDE ports, in millisecs
uint16_t ota_time_window = 20000;          // time to start file upload when ota_flag set to true (after initial boot), in millsecs
uint16_t ota_time_elapsed = 0;             // Counter when OTA active
uint16_t ota_time = ota_boot_time_window;
uint8_t web_otaDone = 0;                   // Web OTA Update
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
void loop() {
  // When OTA flag set via HTML call, time to upload set at 20 sec. via server callback above.  Alter there if more time desired.
  if ((ota_flag) && (!onboarding)) {
    //displayOTA();
    uint16_t ota_time_start = millis();
    while (ota_time_elapsed < ota_time) {
      ArduinoOTA.handle();
      ota_time_elapsed = millis() - ota_time_start;
      delay(10);
    }
    ota_flag = false;
  }
  server.handleClient();
  
  if (!onboarding) {
    uint32_t curMillis = millis();

    if (mqttEnabled && (WIFIMODE > 0 && WiFi.status() == WL_CONNECTED)) {
      mqttConnected = client.connected();
    }

    processTouch();
    switch (activePage) {
      case 0:
        //Default Clock Page  
        if (activePage != lastPage) {
          //Page switch
          if (holdAutoDim) {
            autoDimActive = true;
            holdAutoDim = false;
            //Force brightness update
            activeThresholdMin = 0;
            activeThresholdMax = 0;
          }
          tft.fillScreen(TFT_BLACK);
          lastPage = activePage;
        }
        //Check and adjust brightness if current value overridden - only check once per second
        if ((curMillis - dimLastCheckMillis) > 1000) {
          if (overrideBrightness) {
            //Do not override brightness is alarm is actively sounding
            if (((currentAlarmState == ALARM_IDLE) || (currentAlarmState == ALARM_SNOOZING)) && (curMillis - overrideTimer >= 5000)) {  //Brighten for 5 seconds on override (main page touch)
              overrideBrightness = false;
              setBrightness(holdBrightness);
            }
          } else {
          //Check autoDim and set brightness if threshold crossed
            if (autoDimActive) {  //Only check once per second
              applyDimLevel();
            }
          }
          dimLastCheckMillis = curMillis;
        }

        //Show or update Time
        if (curMillis - prevTime >= 1000) {
          prevTime = curMillis;
          updateClock();
        }

        // Check for active alarms - Excute once per second
        if (curMillis - lastAlarmCheck >= 1000) {
          bool curActiveState = false;
          lastAlarmCheck = curMillis;
          checkAndTriggerAlarm();
          curActiveState = activeAlarmsExist();
          if (curActiveState != activeAlarms) {
            activeAlarmChange = true;
            activeAlarms = curActiveState;
          }
        }
        switch (currentAlarmState) {
          case ALARM_IDLE:
            //just skip
            break;
          case ALARM_TRIGGERED:
            //check for gentleWake and set init volume
            if (useGentleWake) {
              startAlarmSound(gentleWakeIncrement);
              lastGentleTime = curMillis;
            } else {
              startAlarmSound(activeAlarmVol);
            }
            break;
          case ALARM_RINGING:
            //check for gentleWake and increase volume
            if (useGentleWake) {
              if ((gentleWakeActiveVol < activeAlarmVol) && ((curMillis - lastGentleTime) > 5000)) {
                gentleWakeActiveVol = gentleWakeActiveVol + gentleWakeIncrement;
                if (gentleWakeActiveVol <= activeAlarmVol) {
                  sdPlayer.volume(gentleWakeActiveVol);
                } else {
                  sdPlayer.volume(activeAlarmVol);
                  gentleWakeActiveVol = activeAlarmVol;
                }
                lastGentleTime = curMillis;
              }
            }
            break;
          case ALARM_SNOOZING:
            if (millis() >= snoozeEndTime) {
              currentAlarmState = ALARM_TRIGGERED;
            }
            break;
        }
        break;
      case 1:
        //Main Settings Page
        if (activePage != lastPage) {
          //Page switch
          initSettingsSync = true;
          tft.fillScreen(TFT_BLACK);
          drawSettingsPage();
          lastPage = activePage;
        } else if (curMillis - prevTime >= 1000) {
          prevTime = curMillis;
          drawSettingsPage();
        }
        break;
      case 2:
        //Alarm List Page
        if (activePage != lastPage) {
          //Page switch
          initSettingsSync = true;
          tft.fillScreen(TFT_BLACK);
          drawAlarmListPage();
          lastPage = activePage;
        } else if (curMillis - prevTime >= 1000) {
          prevTime = curMillis;
          drawAlarmListPage();
        }
        break;
      case 3:
        //Alarm Edit Page
        if (activePage != lastPage) {
          //Page switch
          initSettingsSync = true;
          tft.fillScreen(TFT_BLACK);
          drawAlarmEditPage();
          lastPage = activePage;
        } else if (curMillis - prevTime >= 1000) {
          prevTime = curMillis;
          drawAlarmEditPage();
        }
        break;
      case 4:
        //Alarm Edit Date Page
        if (activePage != lastPage) {
          //Page switch
          initSettingsSync = true;
          tft.fillScreen(TFT_BLACK);
          drawAlarmEditDatePage();
          lastPage = activePage;
        } else if (curMillis - prevTime >= 1000) {
          prevTime = curMillis;
          drawAlarmEditDatePage();
        }
        break;
      case 5:
        //Alarm Edit Time Page
        if (activePage != lastPage) {
          //Page switch
          initSettingsSync = true;
          tft.fillScreen(TFT_BLACK);
          drawAlarmEditTimePage();
          lastPage = activePage;
        } else if (curMillis - prevTime >= 1000) {
          prevTime = curMillis;
          drawAlarmEditTimePage();
        }
        break;
      case 6:
        //Alarm Edit Repeat Page
        if (activePage != lastPage) {
          //Page switch
          initSettingsSync = true;
          tft.fillScreen(TFT_BLACK);
          drawAlarmEditRepeatPage();
          lastPage = activePage;
        } else if (curMillis - prevTime >= 1000) {
          prevTime = curMillis;
          drawAlarmEditRepeatPage();
        }
        break;

      case 10:
        //Display Test Page
        if ((touchEnabled) || (touchEnabledTest)) {
          uint8_t touchCount = touch.touched(GT911_MODE_POLLING);
          uint16_t x = 0, y = 0;
          if (touchCount > 0) {
            for (uint8_t i = 0; i < touchCount; i++) {
              GTPoint p = touch.getPoint(i);
              uint16_t mapX = p.x;
              uint16_t mapY = p.y;
              transformTouch(mapX, mapY);
              tft.fillCircle((mapX), (mapY), 2, TFT_WHITE);
            }
          }
          delay(20);
        }
        break;
      case 11:
        //Sound Test
        if ((alarmSounding) && (useGentleWake)) {
          if ((gentleWakeActiveVol < activeAlarmVol) && ((curMillis - lastGentleTime) > 5000)) {
            gentleWakeActiveVol = gentleWakeActiveVol + gentleWakeIncrement;
            if (gentleWakeActiveVol <= activeAlarmVol) {
              sdPlayer.volume(gentleWakeActiveVol);
            } else {
              sdPlayer.volume(activeAlarmVol);
              gentleWakeActiveVol = activeAlarmVol;
            }
            lastGentleTime = curMillis;
          }
        }
        break;
      default:
        //do nothing
        break;
    }
    //Handle any required MQTT state publishes (thread-safe)
    if (mqttEnabled && (WIFIMODE > 0 && WiFi.status() == WL_CONNECTED)) {
      if (!mqttConnected) {
        reconnect_soft(); 
      } else {
        client.loop(); 
      }
    }

    if (mqttConnected && !isBooting) {
      unsigned long currentMillis = millis();
      if (currentMillis - lastSyncStepTime > INIT_SYNC_INTERVAL) {
        if (initialSyncRequired) {
          handleInitMqttSync();
        }
        handleQueuedMqttUpdates();
        lastSyncStepTime = currentMillis; // Master clock update
      }
    }    
    //Handle any manual alarm play via MQTT/API
    if (manualAlarmPlay) {
      if ((millis() - manualAlarmStartTime) >= manualAlarmDuration) {
        sdPlayer.stop();
        manualAlarmPlay = false;
      }
    }
    //Save config and reboot if API command received
    if (rebootRequired) {
      sdPlayer.stop();  //In case any sounds are playing
      delay(1000);
      writeConfigFile(true);
    }
  }  
}
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

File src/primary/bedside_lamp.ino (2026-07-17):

/* =================================================================
 * Bedside Lamp: Ultimate bedside dual-lamp and clock
 * July, 2026
 * Version 0.38
 * Copyright ResinChemTech - released under the GPL-3.0 license
 * ================================================================= */
#include <WiFi.h>               //Core WiFi services
#include <WiFiClient.h>         //Arduino ESP Core - creates a client that can connect to an IP address
#include <ESPping.h>            //v1.0.5 - ping remote IP to test connectivity (e.g bulb, display, etc.)
#include <ESPmDNS.h>            //mDNS service for Arduino OTA updates
#include <WebServer.h>          //Local web server (for settings pages)
#include <LittleFS.h>           //Read and write to flash storage
#include <Wire.h>               //I2C
#include <HTTPClient.h>         //For syncing weather from OpenWeatherMap (HTTP Get command) / Controlling bulb (HTTP Post command)
#include <ArduinoJson.h>        //Reading and writing JSON files (e.g. config file)
#include <WiFiUdp.h>            //WiFi UDP functions
#include <ArduinoOTA.h>         //OTA Updates via Arduino IDE
#include <Update.h>             //OTA Updates via web page
#define FASTLED_INTERNAL        //Suppress FastLED SPI/bitbanged compiler warnings (only applies after first compile)
#include <FastLED.h>            //LED control
#include <PubSubClient.h>       //https://github.com/knolleary/pubsubclient  Provides MQTT functions (v2.8)
#include "html.h"               //html code for the web settings pages

#define VERSION "v0.38"
#define APPNAME "BEDSIDE LAMP"
#define WIFIMODE 2                                    // 0 = Only Soft Access Point, 1 = Only connect to local WiFi network with UN/PW, 2 = Both (both needed for onboarding)
#define SERIAL_DEBUG 0                                // 0 = Disable (must be disabled if using RX/TX pins), 1 = enable
//#define MQTTMODE 1                                    // 0 = Disable MQTT, 1 = Enable (will only be enabled if WiFi mode = 1 or 2 - broker must be on same network)

#define FORMAT_LITTLEFS_IF_FAILED true                // DO NOT CHANGE

// ==========================================================================
//  *** REVIEW AND UPDATE THESE VARIABLES TO MATCH YOUR ENVIRONMENT/BUILD ***
// ==========================================================================
//Pin Definitions - Update if your build is different
#define LED_DATA_PIN 4    //GPIO Pin for LED Strip Data Signal
#define TOUCH1_PIN 18     //GPIO Pin for Touch Sensor 1
#define TOUCH2_PIN 19     //GPIO Pin for Touch Sensor 2

//Misc Definitions - Only change if your build is different
#define NUM_LEDS 30       // Default to 30 LED's (can be changed in settings)
#define NUM_LEDS_MAX 99   // Maximum number of LEDs allowed (enforced via web page)
#define MILLI_AMPS 1000   // Limit to 1A if circuit shared with USB charging ports
//MQTT Handling - needed to handle in main loop and to avoid thread conflicts
#define MSK_BULBSTATE   0x0001
#define MSK_BULBMODE    0x0002
#define MSK_BULBCOLOR   0x0004
#define MSK_BULBTEMP    0x0008
#define MSK_BULBBRIGHT  0x0010
#define MSK_LEDSTATE    0x0020
#define MSK_LEDCOLOR    0x0040
#define MSK_LEDBRIGHT   0x0080
#define MSK_TOUCH1_STATE 0x0100
#define MSK_TOUCH1_FUNC  0x0200
#define MSK_TOUCH1_FUNCA 0x0400
#define MSK_TOUCH2_STATE 0x0800
#define MSK_TOUCH2_FUNC  0x1000
#define MSK_TOUCH2_FUNCA 0x2000


/* ================ Default Starting Values ====================================
 * All of these following values can be modified and saved via
 * the web interface and the values below normally do not need to be modified.
 * Using the web settings is the preferred way to change these default values.  
 * Values listed here are just starting values before the config file exists or
 * if it can't be read.
 ===============================================================================*/
//----------------------------------
//Local Variables (wifi/onboarding)
//----------------------------------
String deviceName = "BedsideLamp01";  // Default Device Name - 16 chars max, no spaces.
String wifiHostName = deviceName;     // Use Device Name for wifi and mDNS name
String wifiSSID = "";                 
String wifiPW = "";
byte macAddr[6];                      // Array of device mac address as hex bytes (reversed)
String strMacAddr;                    // Formatted string of device mac address
String baseIPAddress;                 // Device assigned IP Address (this controller)
bool onboarding = false;              // Will be set to true if no config file or wifi cannot be joined

//----------------------------------
//Local Variables (MQTT/Discovery)
//----------------------------------
//  MQTT will only be used if a server address other than '0.0.0.0' is entered via portal
byte mqttAddr_1 = 0;
byte mqttAddr_2 = 0;
byte mqttAddr_3 = 0;
byte mqttAddr_4 = 0;
int mqttPort = 0;
String mqttIPAddress = "0.0.0.0";   //IP address of MQTT broker (will be concatenated from 4 vars above)
String mqttClient = "blprimary'";   //Unique client name for MQTT
String mqttUser = "myusername";     //MQTT broker user name
String mqttPW = "mypassword";       //MQTT broker password
uint32_t mqttTelePeriod = 60;       //seconds - how often MQTT values published (outside of local state changes)
uint32_t lastMqttRetryAttempt = 0;  //Non-blocking handler for MQTT reconnection
const int MQTT_RETRY_DELAY = 5000;  //Delay (ms) between reconnect attempts
String mqttTopicSub ="bedlamp";     //Can be changed via web app (preferred method)
String mqttTopicPub = "bedlamp";    //Can be changed via web app (preferred method)
bool mqttEnabled = false;           //Will be enabled/disabled depending on whether a valid IP address is defined in Settings (0.0.0.0 disables MQTT)
bool mqttConnected = false;         //Will be enabled if defined and successful connnection made.  This var should be checked upon any MQTT action.
bool forceMQTTUpdate = false;       //For forcing MQTT update on state change
bool initialSyncRequired = false;   //Flag for initial publish of MQTT data after boot
bool rebootRequired = false;        //Needed for saveconfig command to allow return vals and to flush buffer before a reboot
bool touch1MqttLatched = false;     //For publishing touch sensor state changes via MQTT
bool touch2MqttLatched = false;
int syncStep = 0;
unsigned long lastSyncStepTime = 0;
volatile uint32_t mqttUpdateMask = 0;  //Volatile so it can be updated by out-of-thread background tasks
const int INIT_SYNC_INTERVAL = 100;    //100ms between publishing

struct DiscoverySettings {        //Structure for HA MQTT Discovery 
  bool exists = false;
  String deviceName = "";
  bool lightBulb = true;
  bool ledStrip = true;
  bool display = true;
  bool touch = true;
  bool alarms = true;
  bool diagnostics = true;
};
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
